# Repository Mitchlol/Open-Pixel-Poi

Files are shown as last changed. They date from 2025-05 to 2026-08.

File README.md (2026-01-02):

<h1>
Open Pixel Poi

</h1>

<h4>
  <a href="https://openpixelpoi.com/">Store</a>
  ·
  <a href="./Firmware/MANUAL.md">User Guide</a>
  ·
  <a href="./Hardware/3D Printable Body/README.md">3D Models</a>
  ·
  <a href="./Hardware/Assembly/README.md">Assembly</a>
  ·
  <a href="./Software/README.md">Mobile App</a>
  ·
  <a href="https://mitchlol.github.io/#openpixelpoi">Firmware Tool</a>
  ·
  <a href="https://discord.gg/WpPJEskEuM">Discord</a>
  ·
  <a href="https://www.instagram.com/openpixelpoi">Instagram</a>
</h4>

Open Pixel Poi  is an open source, 3D printable, LED pixel Poi, based around ESP32, WS2812B, and FFF/FDM manufacturing.
Designed to be simple, afforable, repairable, and customizable.
<div>
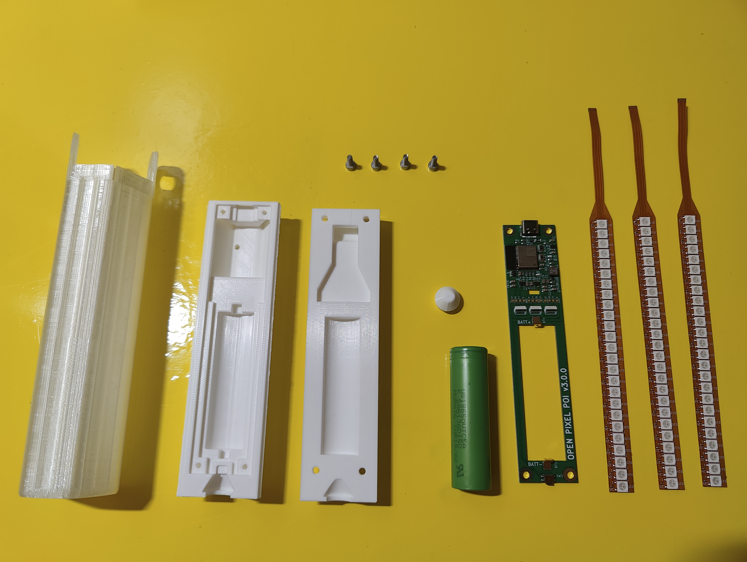
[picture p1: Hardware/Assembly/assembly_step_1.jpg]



</div>

#### License
[Licensed  with GPLv3](https://www.gnu.org/licenses/gpl-3.0.en.html)
Suggested donation of 5$ per set of Poi built via [paypal](https://www.paypal.com/donate/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) when build without purchasing PCBs from our <a href="https://openpixelpoi.com/">Store</a>.

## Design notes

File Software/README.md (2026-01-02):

# Open Pixel Poi Software
<div>





</div>

## About
This app is written using flutter, a multi-platform framework. It is designed to run on mobile sized screens, but will work on anything. Currently, I have built the app for [Android](#android-releases), [Windows](#windows-releases), and [Web](#web-releases).

This app is the only way transmit patterns to the poi hardware.

All patterns are images. To import a new pattern to the app, it must be a bitmap/png/jpg format. Then simply tap/click/etc the pattern to overwrite the currently active pattern on all connected poi. See the [pattern info doc](./PATTERN_INFO.md) for more details.

App use may require a poi [firmware update](https://mitchlol.github.io/#openpixelpoi)

###### Tips & Tricks
- Select multiple devices to connect to multiple devices.
- Long press scan to proceed to app without any connections.
- Long press a pattern to see it's size, or delete/flip/mirror it.
- Selecting the ∞ pattern slot will trigger auto pattern looping.
- Long press the app name on the patterns page to enter the secret [device settings](../Firmware/CONFIG.md) page.
- The text pattern creation input only accepts capital letters.
- When creating stacked patterns, be mindful of the widths, if the least common multiple is greater than 400, it will crop.
- Buy a \$2000 macbook, a \$1000 iphone and a dev license to build the app for iOS.

## Android Releases
###### ⚠️Uninstall the app  before switching versions.⚠️
- [Open Pixel Poi v2.0.0](https://github.com/Mitchlol/Open-Pixel-Poi/raw/refs/heads/main/Software/open_pixel_poi_v2.0.0.apk)
- [Open Pixel Poi v1.0.0](https://github.com/Mitchlol/Open-Pixel-Poi/raw/refs/heads/main/Software/open_pixel_poi_v1.0.0.apk)

## Windows Releases
- [Open Pixel Poi v2.0.0](https://github.com/Mitchlol/Open-Pixel-Poi/raw/refs/heads/main/Software/open_pixel_poi_windows_v2.0.0.zip)
- [Open Pixel Poi v1.0.0](https://github.com/Mitchlol/Open-Pixel-Poi/raw/refs/heads/main/Software/open_pixel_poi_windows_v1.0.0.zip)

## Web Releases
> [!TIP]
> Web bluetooth api is limited to a single device connection at a time.
> Also, it is unspported on iOS 🤦‍♂️.

- [Open Pixel Poi Web v2.0.0](https://mitchlol.github.io/opp_flutter_app_2.0/index.html)
- [Open Pixel Poi Web v1.0.0](https://mitchlol.github.io/opp_flutter_app_1.0/index.html)

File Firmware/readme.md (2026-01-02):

# Open Pixel Poi Firmware

##### Links
- [User Manual](./MANUAL.md)
- [Firmware Flashy Thing](https://mitchlol.github.io/#openpixelpoi)

##### Firmware info
This is the firmware, it is an arduino project designed to be built in platformio.

Platformio should get all the correct dependancies automatically based on the config, but in case it doesn't here are the details.
It uses the neopixelbus library.
It requires the esp32 boards to be installed, I reccomend v2.0.12 as newer versions cause led glitches.
When builiding, use the XIAO_ESP32C3 board for the gpio config to line up. All the other board settings can be default.

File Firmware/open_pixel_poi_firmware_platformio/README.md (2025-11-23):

# Compiling Info
1. Connect your ESP32 PCB to your computer via USB, on windows it should show up as "USB Serial Device (COM#)" with the "#" being a random number.
1. Open this folder up in VSCode with the PlatformIO plugin stalled.
1. Hit the -> arrow button on the bottom bar to compile and upload the firmware to your PCB.

All the library dependencies and board config is contained in the platformio.ini file in this folder.

# Note for self: Export a compiled firmware to web-based firmware flashy tool.
1. Hit the -> arrow button on the bottom bar to compile and upload the firmware to your PCB.
1. copy .pio/build/seeed_xiao_esp32c3/firmware.bin to opp_firmware folder in the mitchlol.github.io project, replacing the old one.
1. update the manifest.json in that same folder with the current date to have some minimal tracking.

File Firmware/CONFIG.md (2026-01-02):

# Notes about the config.h and app overrides

The [config.h](./open_pixel_poi_firmware_platformio/src/config.h) file contains all the constant perameters for the firmware. Most of these should never be changed, unless you are building custom hardware.

Some of the fields however can be changed via the app, such as renaming your device, changing the led quantity or type, or even changing your 6 speed options.

To enter to enter the device settings page, long press the app name on the patterns page.

Settings changed via the app will permanently overwrite the default config.h, unless a full chip erase is done. My firmware flashing webpage does a full erase. The default upload button in platformio does not.

To get a fully custom config, simply change what you need, recompile, and upload.

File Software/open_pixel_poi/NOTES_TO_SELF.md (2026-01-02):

# Dear me
Compiling for web doesn't require any code changes, however web bluetooth doesn't work on your windows desktop, so test with your phone or something else. When releasing a build make sure to update the base url at the top of the index.html in the built web folder. 

Compiling for windows requires switching to flutter_blue_plus_windows see commented out stuff.

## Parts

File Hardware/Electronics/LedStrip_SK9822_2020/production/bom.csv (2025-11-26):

Designator | Footprint | Quantity | Value | LCSC Part #
LED1, LED10, LED11, LED12, LED13, LED14, LED15, LED16, LED17, LED18, LED19, LED2, LED20, LED21, LED22, LED23, LED24, LED25, LED26, LED27, LED28, LED29, LED3, LED30, LED31, LED32, LED33, LED34, LED35, LED36, LED37, LED38, LED39, LED4, LED40, LED41, LED42, LED43, LED44, LED45, LED46, LED47, LED48, LED49, LED5, LED50, LED51, LED52, LED53, LED54, LED55, LED6, LED7, LED8, LED9 | LED-SMD_6P-L2.0-W2.0-P0.80-TL | 55 | SK9822-EC20 | C2909059

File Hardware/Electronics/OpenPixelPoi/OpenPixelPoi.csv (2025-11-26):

Id | Designator | Footprint | Quantity | Designation | Supplier and ref
1 | C6,C7 | C_0402_1005Metric | 2 | 22u
2 | R5 | R_0603_1608Metric | 1 | 1k
3 | R4 | R_0603_1608Metric | 1 | 10k
4 | C1 | C_0805_2012Metric | 1 | 100n
5 | U3 | ESP32-C3-MINI-1_EXP | 1 | ESP32-C3-MINI-1-N4
6 | SW2,SW1 | SW_SPST_B3U-1000P | 2 | SW_Push
7 | J1 | JST_PH_B3B-PH-K_1x03_P2.00mm_Vertical | 1 | Conn_01x03_Socket
8 | R2,R1 | R_0603_1608Metric | 2 | 5k1
9 | U5 | SOT-223-3_TabPin2 | 1 | TLV1117-33
10 | F1 | Fuse_1206_3216Metric | 1 | Polyfuse_Small (1A)
11 | U1 | SOT-666 | 1 | USBLC6-2P6
12 | D1 | LED_0603_1608Metric | 1 | LED
13 | SW3 | Panasonic_EVQPUL_EVQPUC | 1 | SW_Push
14 | R3 | R_0603_1608Metric | 1 | 100k
15 | J6 | USB_C_Receptacle_HRO_TYPE-C-31-M-12 | 1 | USB_C_Receptacle_USB2.0_16P
16 | Q1 | SOT-23 | 1 | BSS138

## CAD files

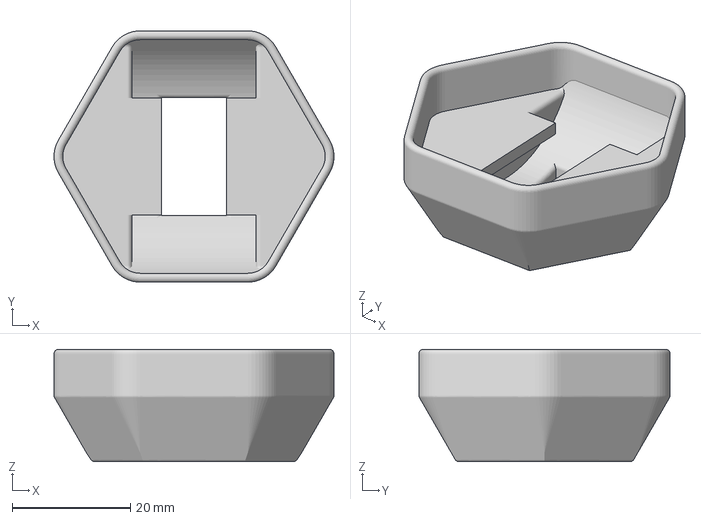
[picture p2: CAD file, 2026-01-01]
Hardware/3D Printable Body/Extras/Open Pixel Poi - Shell Cap - Hex.3mf
47.4 x 42.5 x 19.0 mm

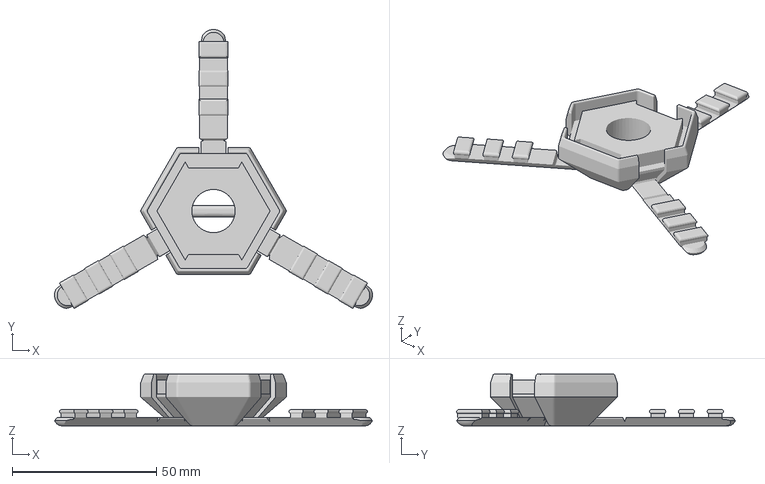
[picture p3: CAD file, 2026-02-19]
Hardware/3D Printable Body/Open Pixel Poi - Shell Cap - Snap B.3mf
110.3 x 96.8 x 18.0 mm

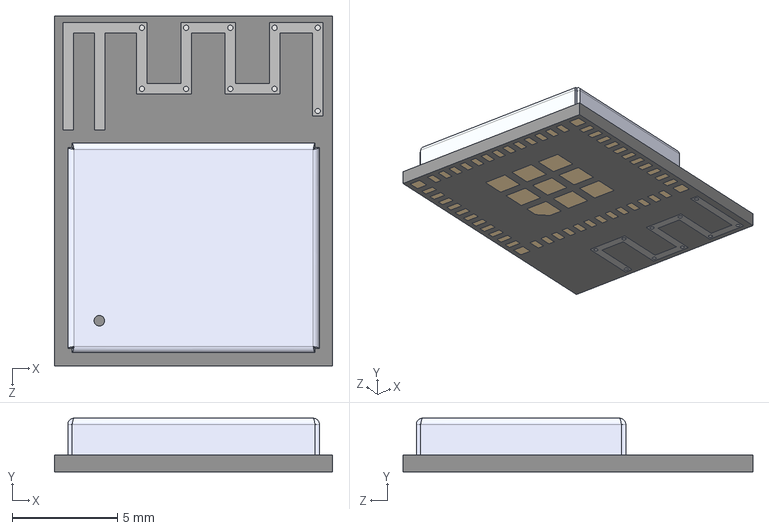
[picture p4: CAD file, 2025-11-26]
Hardware/Electronics/OpenPixelPoi/ESP32_C3_MINI_1_N4 (v2)/ESP32-C3-MINI-1-N4.step
13.2 x 2.55 x 16.6 mm

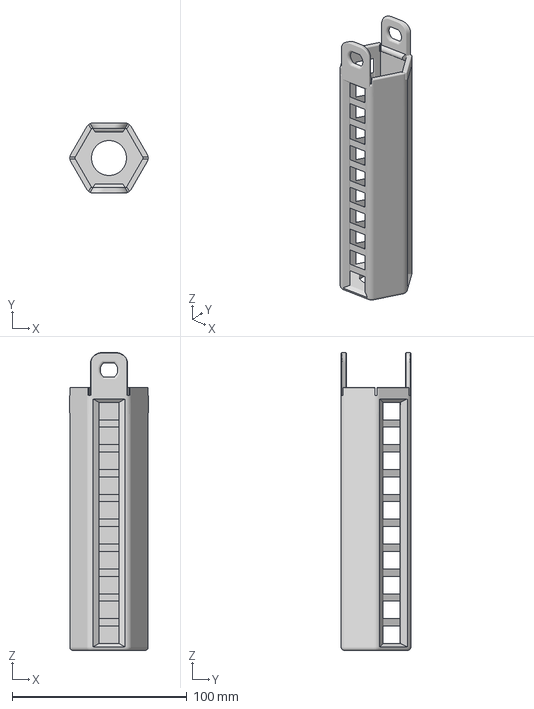
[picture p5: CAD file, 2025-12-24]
Hardware/3D Printable Body/Extras/Open Pixel Poi - Shell - Hex Holes - 55 Pixel.3mf
44.9 x 40.0 x 170.5 mm

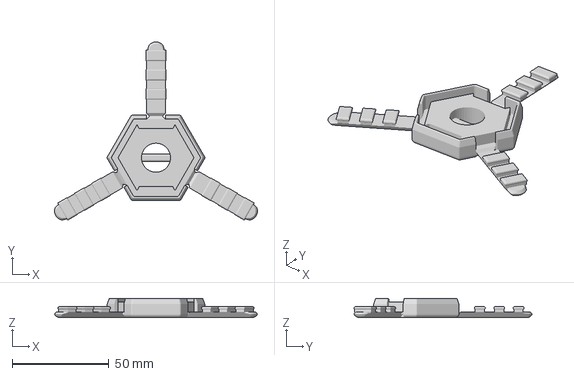
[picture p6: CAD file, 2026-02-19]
Hardware/3D Printable Body/Open Pixel Poi - Shell Cap - Snap A.3mf
104.9 x 92.1 x 10.0 mm

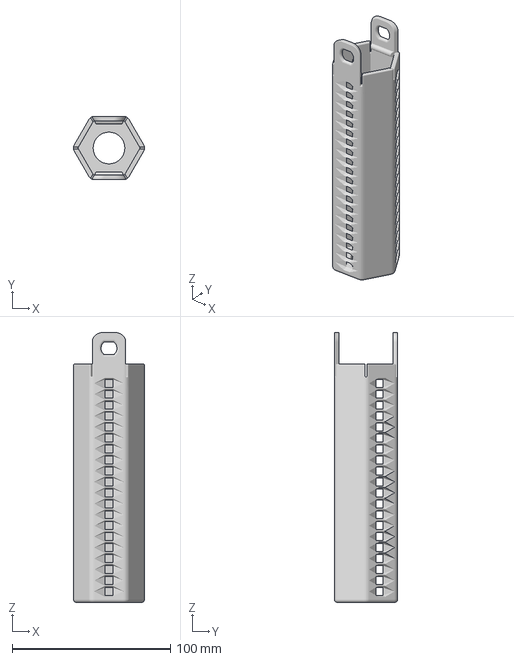
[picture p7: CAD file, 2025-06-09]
Hardware/3D Printable Body/Extras/Open Pixel Poi - Shell - Hex Holes.3mf
45.0 x 40.0 x 170.5 mm

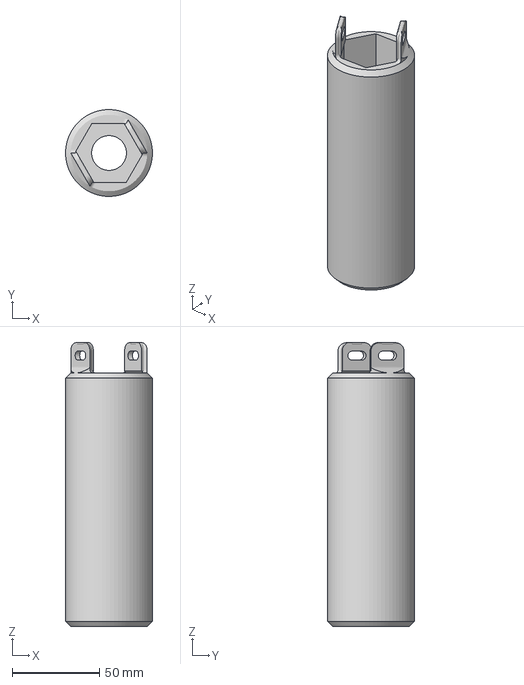
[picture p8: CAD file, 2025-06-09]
Hardware/3D Printable Body/Extras/Open Pixel Poi - Shell - Round Superdiffuser.3mf
49.9 x 49.9 x 163.0 mm

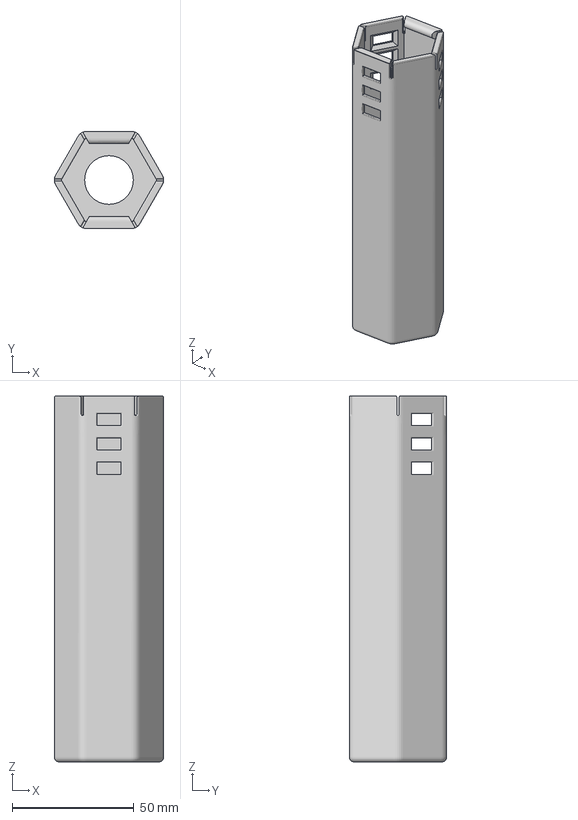
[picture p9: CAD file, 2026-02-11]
Hardware/3D Printable Body/Open Pixel Poi - Shell - Snap.3mf
45.0 x 40.0 x 150.5 mm

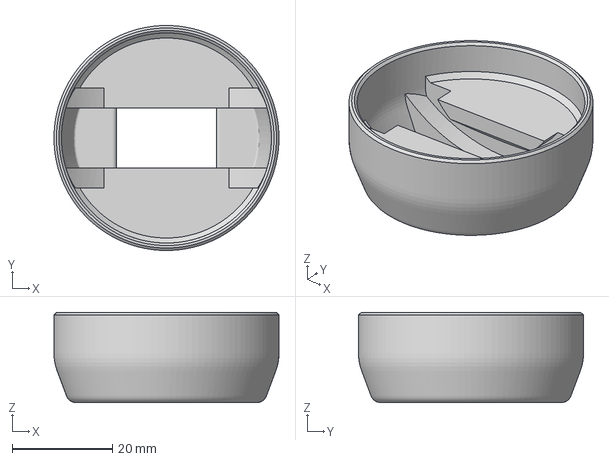
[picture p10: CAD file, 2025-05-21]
Hardware/3D Printable Body/Extras/Open Pixel Poi - Shell Cap - Round.3mf
45.0 x 45.0 x 18.0 mm

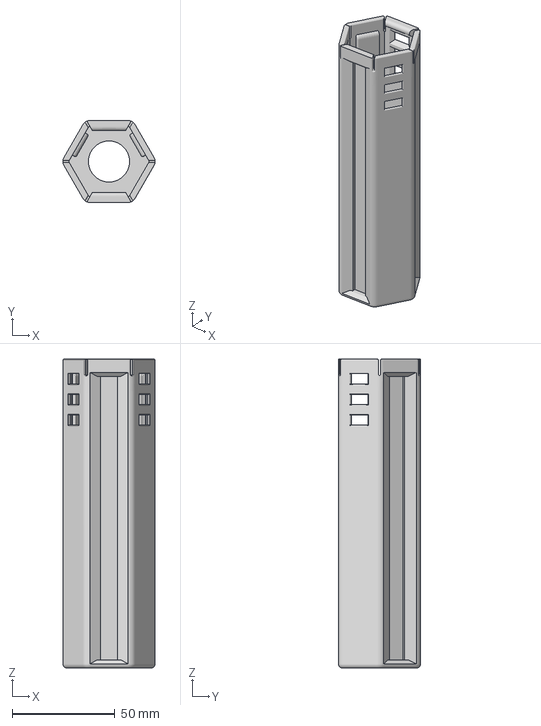
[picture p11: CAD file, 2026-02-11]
Hardware/3D Printable Body/Open Pixel Poi - Shell - Snap - 55 Pixel.3mf
45.0 x 40.0 x 150.5 mm

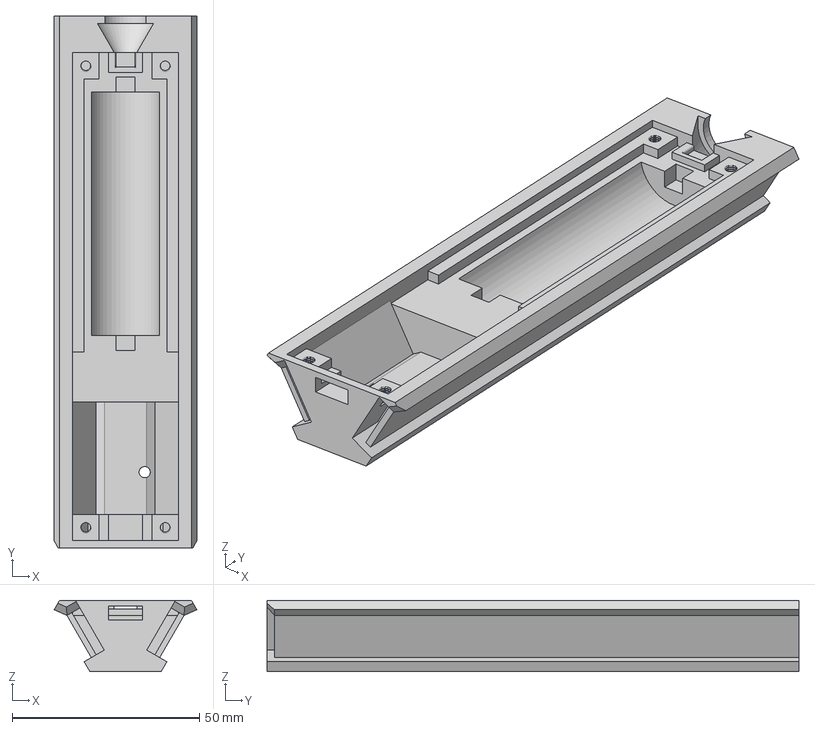
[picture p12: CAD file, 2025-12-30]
Hardware/3D Printable Body/Open Pixel Poi - Body - Top.3mf
38.1 x 142.0 x 19.0 mm

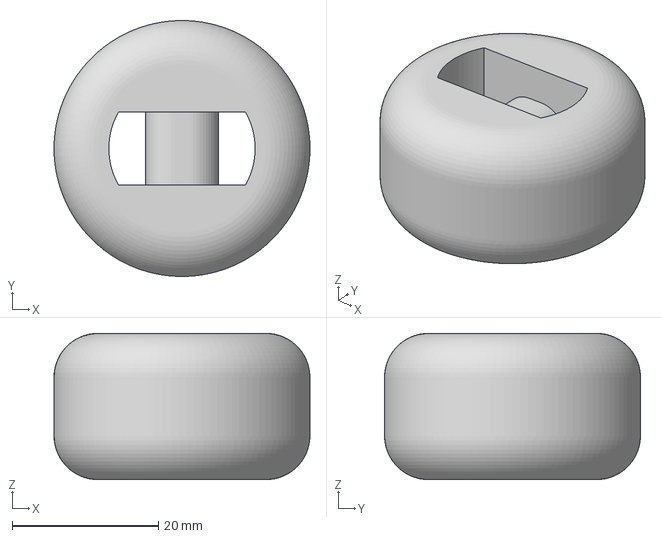
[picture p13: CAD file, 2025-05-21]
Hardware/3D Printable Body/Extras/Poi Knob v2.3mf
35.0 x 35.0 x 20.0 mm

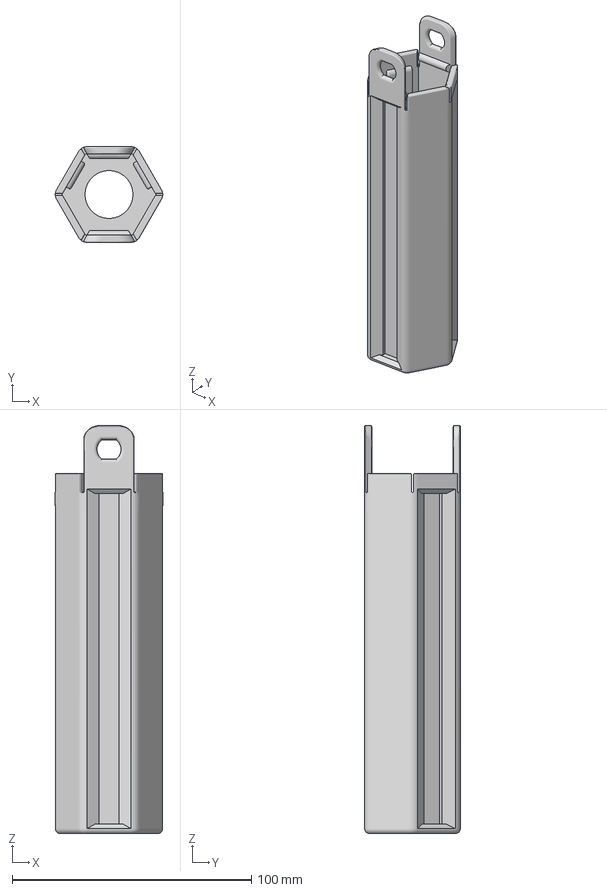
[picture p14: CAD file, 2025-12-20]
Hardware/3D Printable Body/Open Pixel Poi - Shell - Hex - 55 Pixel.3mf
45.0 x 40.0 x 170.5 mm

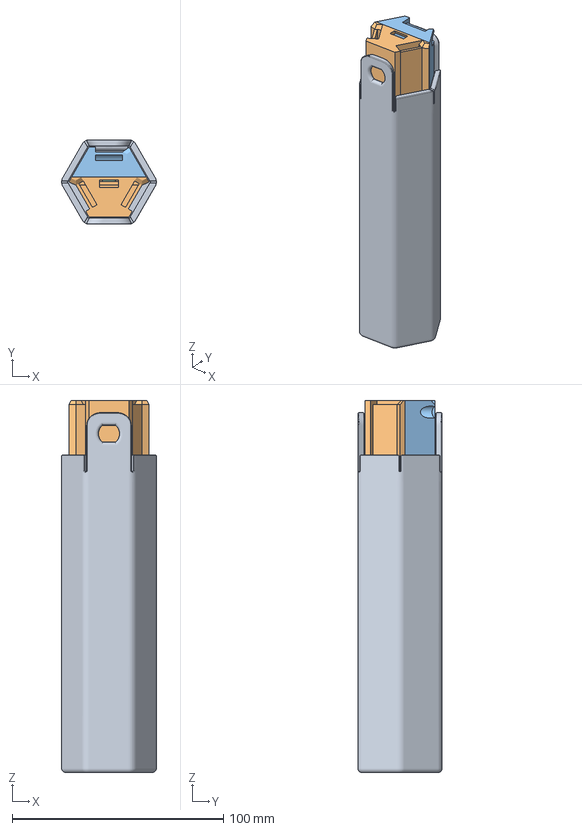
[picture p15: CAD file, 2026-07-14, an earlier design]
Hardware/3D Printable Body/OldFiles/Open Pixel Poi - All Parts In One File.3mf
45.0 x 40.0 x 176.2 mm

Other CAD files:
Hardware/3D Printable Body/Open Pixel Poi - Shell Cap - Snap C.3mf
Hardware/3D Printable Body/OldFiles/Open Pixel Poi - Shell - Hex.3mf
Hardware/3D Printable Body/OldFiles/Open Pixel Poi - Shell - Round Diffused.3mf
Hardware/3D Printable Body/Extras/Poi Knob v1.3mf

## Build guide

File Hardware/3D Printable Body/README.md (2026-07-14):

# Open Pixel Poi - 3D Printed Body

## Main Body
Print all the main body parts in **PLA** or any other rigid material. Slicer profiles such as layer height an infill are not important, just make sure you can do the overhangs. The individual body files have been pre-oriented so that no supports/brims/rafts/etc are required, see the section on orientation below to confirm your orientation. You need 1 of each part per poi, or 2 of each for a pair.
###### Main body parts are:
1. [Open Pixel Poi - Body - Top](<https://github.com/Mitchlol/Open-Pixel-Poi/raw/refs/heads/main/Hardware/3D%20Printable%20Body/Open%20Pixel%20Poi%20-%20Body%20-%20Top.3mf>)
1. [Open Pixel Poi - Body - Bottom](<https://github.com/Mitchlol/Open-Pixel-Poi/raw/refs/heads/main/Hardware/3D%20Printable%20Body/Open%20Pixel%20Poi%20-%20Body%20-%20Bottom.3mf>)
1. [Open Pixel Poi - Body - Button](<https://github.com/Mitchlol/Open-Pixel-Poi/raw/refs/heads/main/Hardware/3D%20Printable%20Body/Open%20Pixel%20Poi%20-%20Body%20-%20Button.3mf>)

## Outer Shell
The outer shell must be printed in **Clear / Transparent TPU**. All shell files are preoriented and do not require any supports/brims/rafts/etc, but I reccomend the "avoid crossing perimiters" settings to reduce stringing. See the section on orientation below to confirm your orientation. The shells look nice in 10% gyroid or 3d honeycomb infill IMO. You need 1 shell & 1 cap per poi, so that means 4 parts for a pair.

For the cap, pick whichever version you preffer, they are all cross compatible. If you want a different mounting situation on these caps, and don't know how to model it yourself, send a message in the discord channel, and I can likely help you out.

###### Shells versions are:
1. **25 Pixel (Standard) Shell:** [Open Pixel Poi - Shell - Snap](<https://github.com/Mitchlol/Open-Pixel-Poi/raw/refs/heads/main/Hardware/3D%20Printable%20Body/Open%20Pixel%20Poi%20-%20Shell%20-%20Snap.3mf>)
1. **55 Pixel (HD) Shell:** [Open Pixel Poi - Shell - Snap - 55 Pixel](<https://github.com/Mitchlol/Open-Pixel-Poi/raw/refs/heads/main/Hardware/3D%20Printable%20Body/Open%20Pixel%20Poi%20-%20Shell%20-%20Snap%20-%2055%20Pixel.3mf>)

###### Cap options are:
1. **Snap Cap Flat:** [Open Pixel Poi - Shell Cap - Snap A](<https://github.com/Mitchlol/Open-Pixel-Poi/raw/refs/heads/main/Hardware/3D%20Printable%20Body/Open%20Pixel%20Poi%20-%20Shell%20Cap%20-%20Snap%20A.3mf>)
1. **Snap Cap Tapered:** [Open Pixel Poi - Shell Cap - Snap B](<https://github.com/Mitchlol/Open-Pixel-Poi/raw/refs/heads/main/Hardware/3D%20Printable%20Body/Open%20Pixel%20Poi%20-%20Shell%20Cap%20-%20Snap%20B.3mf>)
1. **Snap Cap Tapered 6.75mm Though-Hole:** [Open Pixel Poi - Shell Cap - Snap C](<https://github.com/Mitchlol/Open-Pixel-Poi/raw/refs/heads/main/Hardware/3D%20Printable%20Body/Open%20Pixel%20Poi%20-%20Shell%20Cap%20-%20Snap%20C.3mf>)

## Orientation
The parts all print without supports when oriented like this. Take special note of orientation the bottom half of the body, the led groove is an overhang rather than requiring supports.

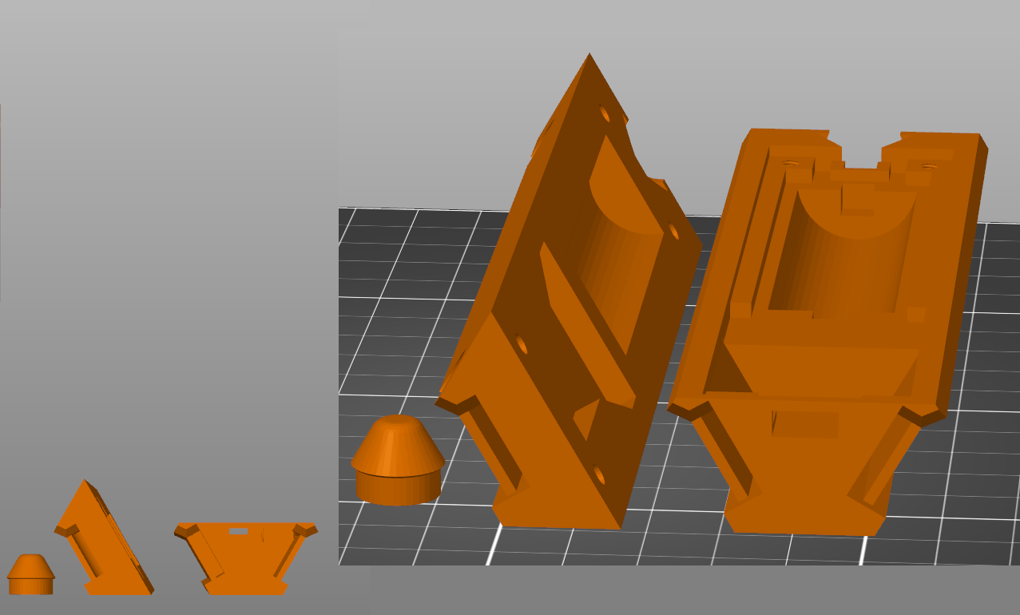
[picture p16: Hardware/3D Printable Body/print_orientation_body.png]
Body orientation
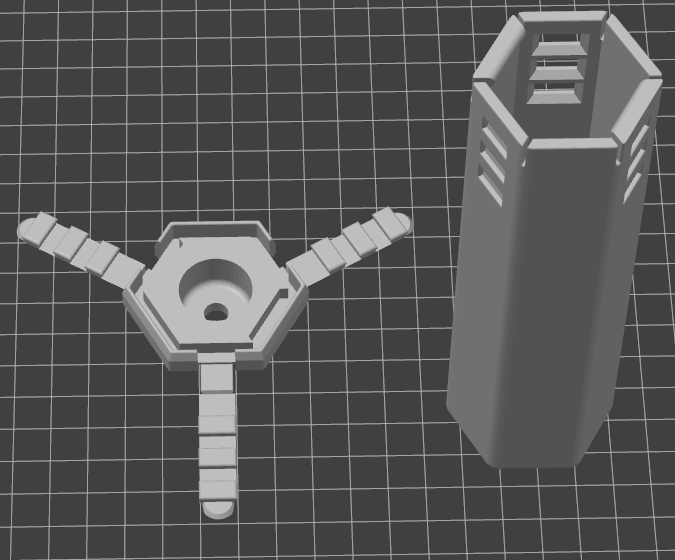
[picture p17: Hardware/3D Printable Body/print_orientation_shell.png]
Shell orientation


## Extras
The [Extras](./Extras/README.md) folder contains poi knobs, and whatever else seems relevant to upload. Nothing in this folder is required to have a functional poi, but it is worth having a look.

## OldFiles
If you are looking for the older shell files, they are now deprecated, but I dumped them all in the [OldFiles folder](./OldFiles)

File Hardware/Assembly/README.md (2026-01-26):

# Open Pixel Poi Assembly Guide

## intro

This is basic assembly guide, and while assembly should be intuitive, this guide includes a few tips, tricks, and order of operations optimizations.

Assembly is identical for both the 25 & 55 pixel LED strips. If you wish to solder your own LED strips or have a 2.2.1 version of the kit, see the <a href="./2.2.1/README.md">2.2.1 Assembly Guide</a> 

## Step 1: 
### Gather your parts
For a single poi you will need:
1. 3D Printed outer shell (clear TPU) - 1x
1. 3D Printed body top (PLA) - 1x
1. 3D Printed body bottom (PLA) - 1x
1. 3D Printed button (PLA) - 1x
1. M3 x 8mm Hex Socket Head Cap Screw - 4x
1. 18650 Li-Ion battery - 1x
1. Open Pixel Poi PCB - 1x
1. Open Pixel Poi LED Strip - 3x

wiring

## Step 2
### Insert 2 led stips. 
Feed 2 led strips in though the holes at the top of the 3D printed top body piece.
wiring

## Step 3
### Connect 2 LED strips to the PCB
Ensure the black levers on the connectors are lifted up (perpendicular) from the PCB.  
Insert the FPC(ribbon cable) connections into the 2 outer connectors.  
Be gentle, minimal force is required, if it catches on something, pull back and try again.  
Secure the ribbon cables by rotating/folding/pushing the black levers down, so they are parallel with the board.  
The LED connections work both ways (like USB-C). I reccomend matching the directions in the photo with the yellow background to avoid twists.  
Look at the 2nd photo with red markings for a generic close up view of the insertion and lever mechanism.  
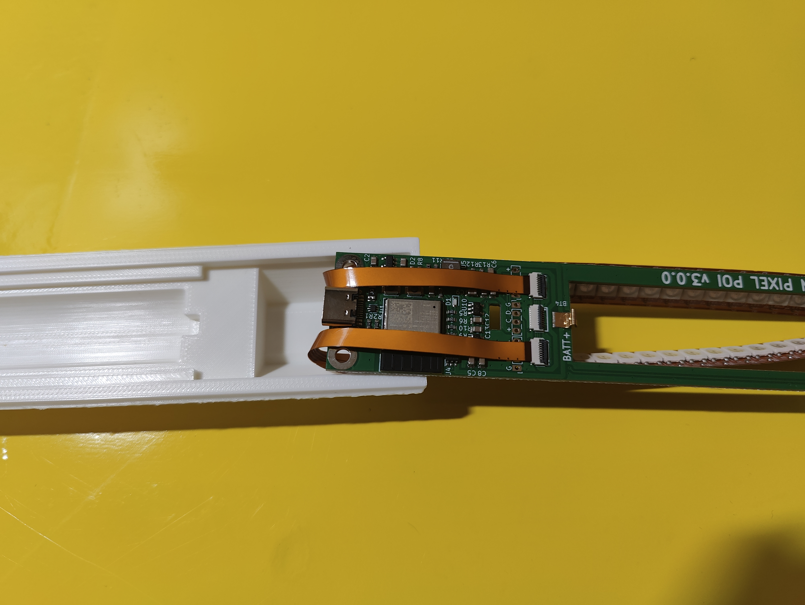
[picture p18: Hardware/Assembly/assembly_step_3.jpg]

wiring

## Step 4
### Thread 3rd led strip through the PCB
Thread 3rd led strip through the small hole in the PCB.  
Give yourself plenty of slack.  
wiring

## Step 5
### Connect the 3rd LED strip to the PCB
Same as step 3, but using the middle connector.  
Once connected, pull the slack back through the hole in the PCB.  
The LED connections work both ways (like USB-C). I reccomend matching the directions in the photos to avoid twists.  
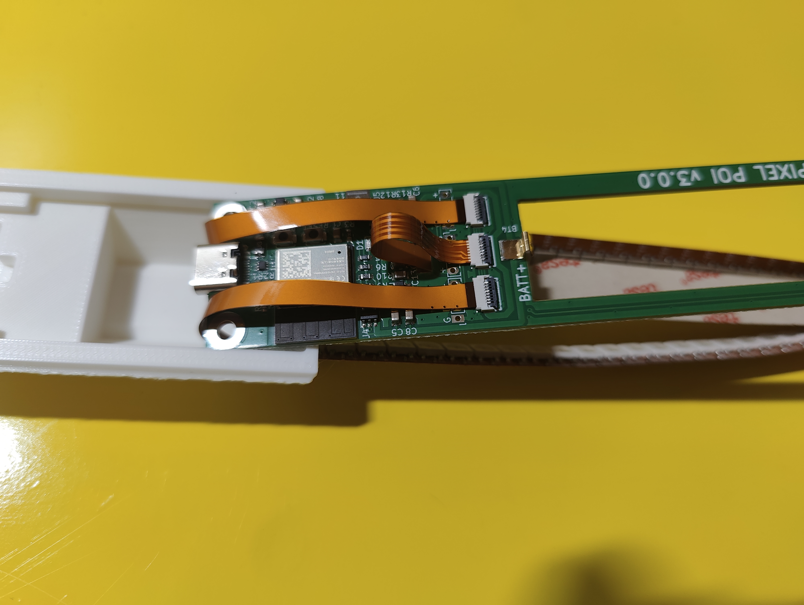
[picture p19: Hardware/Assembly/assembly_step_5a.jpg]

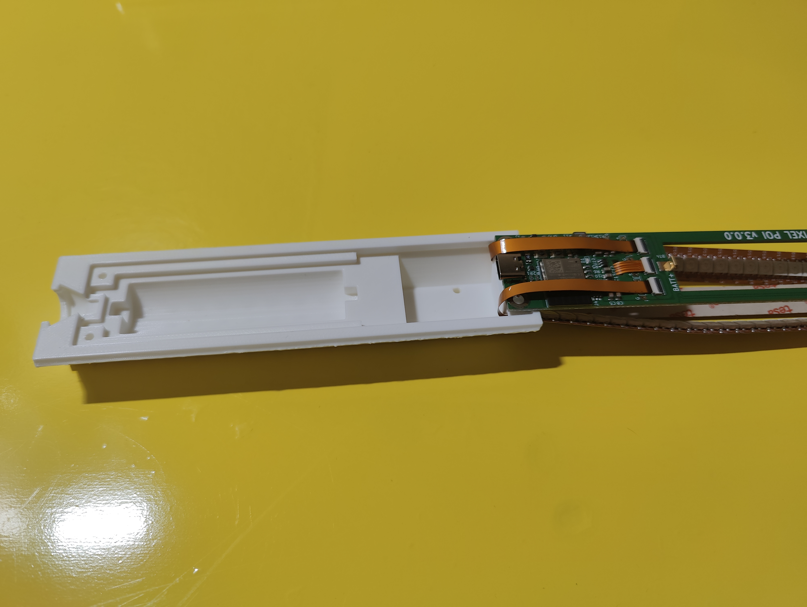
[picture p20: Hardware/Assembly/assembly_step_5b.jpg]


## Step 6
### Insert the battery into the top of the body
Push the battery into the body, making sure the positive end is towards the USB port, and lines up with the batt+ label on the board.  
It is a tight fit, this is intentional.  
It goes in easiest if you slide it in all at once, rather than one end first.  
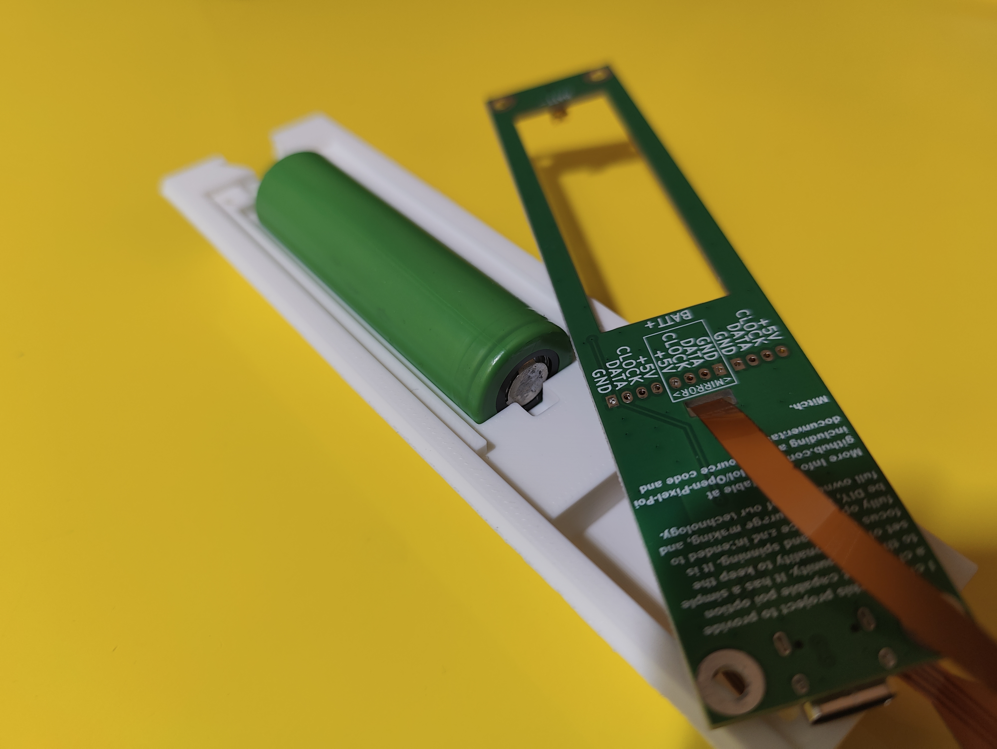
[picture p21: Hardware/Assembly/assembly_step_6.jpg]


## Step 7
### Slot in the PCB
Order is important here.  
First slide the usb port into the usb port hole at the top of the poi, while keeping the switch end of the board elevated.  
Then, carefully lever down the board over the battery, this will turn the poi on.  
Finally, make sure the bottom (and sides) of the pcb are fully seated and flush with the body.  
This is often tight as well and may snap in.  
You can turn the poi off with the switch see the [user manual](../../Firmware/MANUAL.md)
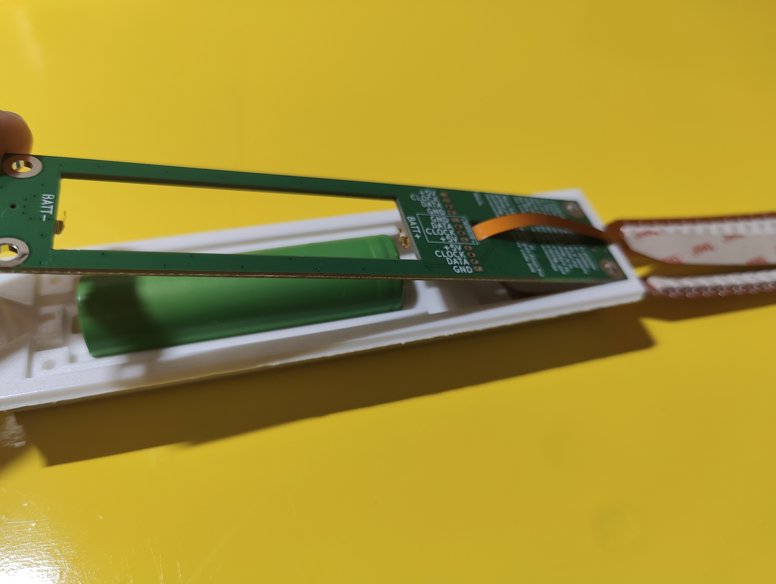
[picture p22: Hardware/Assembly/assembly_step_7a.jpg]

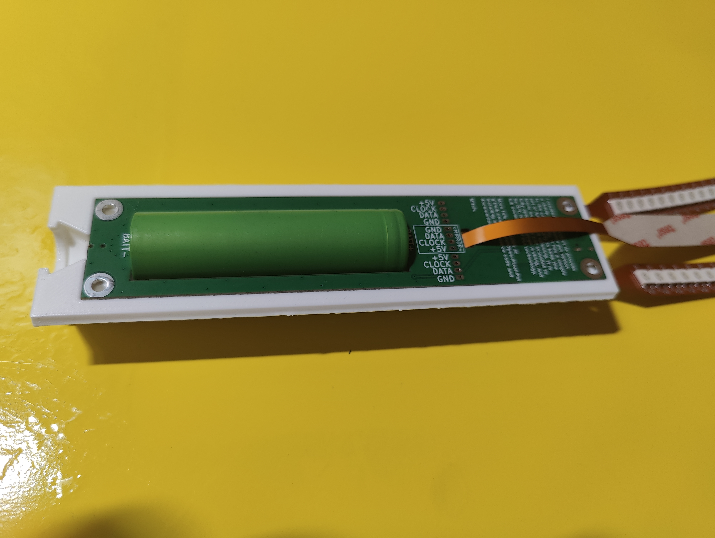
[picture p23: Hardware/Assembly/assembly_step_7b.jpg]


## Step 8
### Snap the button into body
Push the button into the body, it is a snap fit.
> [!CAUTION]
> **Take extra care to avoid contact with the switch on bottom of the board!**
> **It can break easy.**

> [!TIP]
> After writing this guide, I came across a potentialy safer alternative assembly method. Place the button in before putting the PCB in, then hold the body vertically such that gravity lets the button fall to the down position. Then snap the board in without fear of tearing the switch off the pcb, as gravity holds the button away. Maybe this will be useful if someone is assembling many kits.

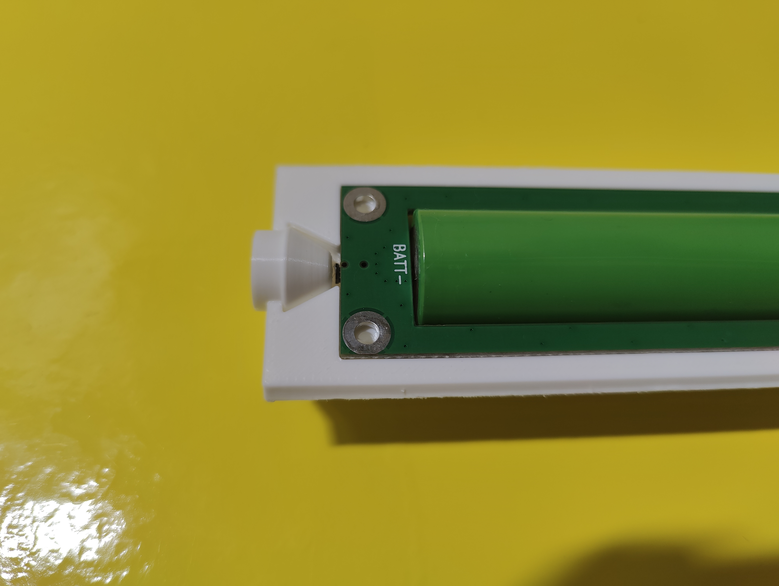
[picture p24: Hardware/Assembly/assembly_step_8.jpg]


## Step 9
### Thread the 3rd led strip through the bottom of the body
Thread the 3rd led strip through the hole at the top of the bottom body half, from the inside to out, make sure it is twisted the right way.
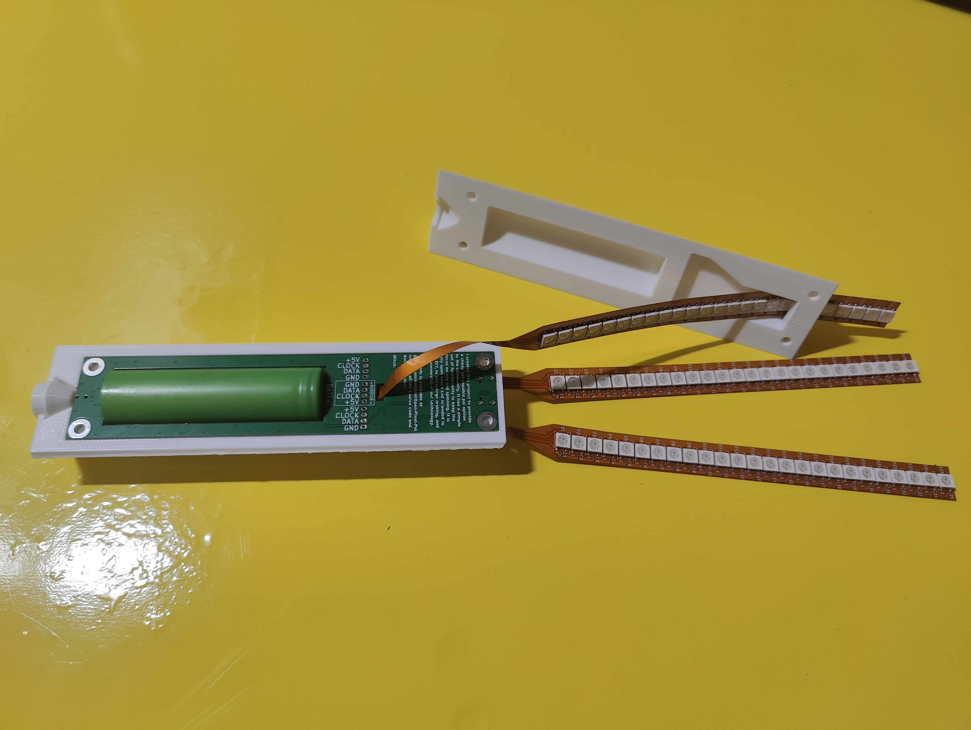
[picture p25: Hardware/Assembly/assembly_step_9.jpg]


## Step 10
### Push the 2 body halves together
Once again, the battery is snug. Make sure the LED stips don's get pinched.
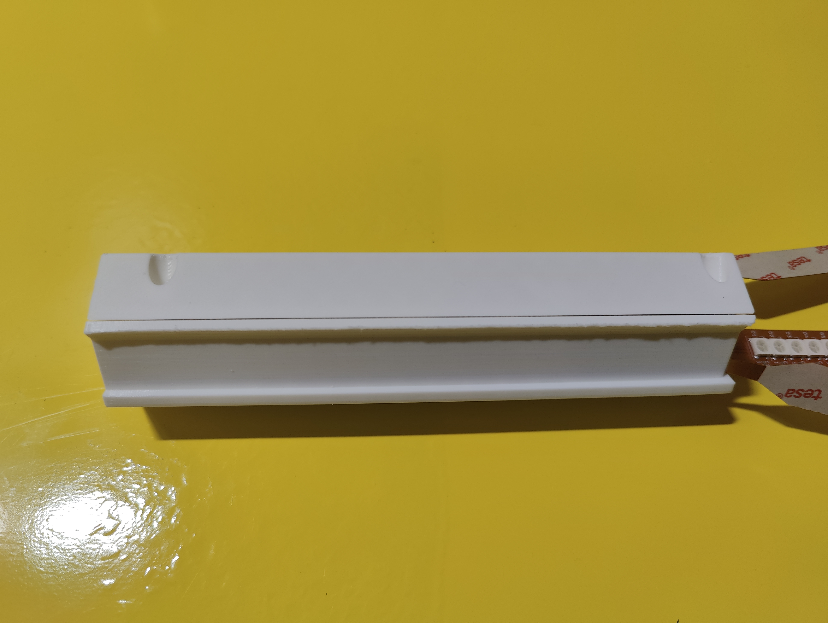
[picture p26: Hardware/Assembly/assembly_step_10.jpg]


## Step 11
### Screw the two halves together
These screws are going directly into a 3d print, so be gentle, you don't want to strip the threads. You can hold it up to the light to make sure there is no visible gap between the 2 halfs, to know it is snug.

Alternativley, you can just wrap the sucker in packing tape, just make sure you do it after sticking on the LEDs.
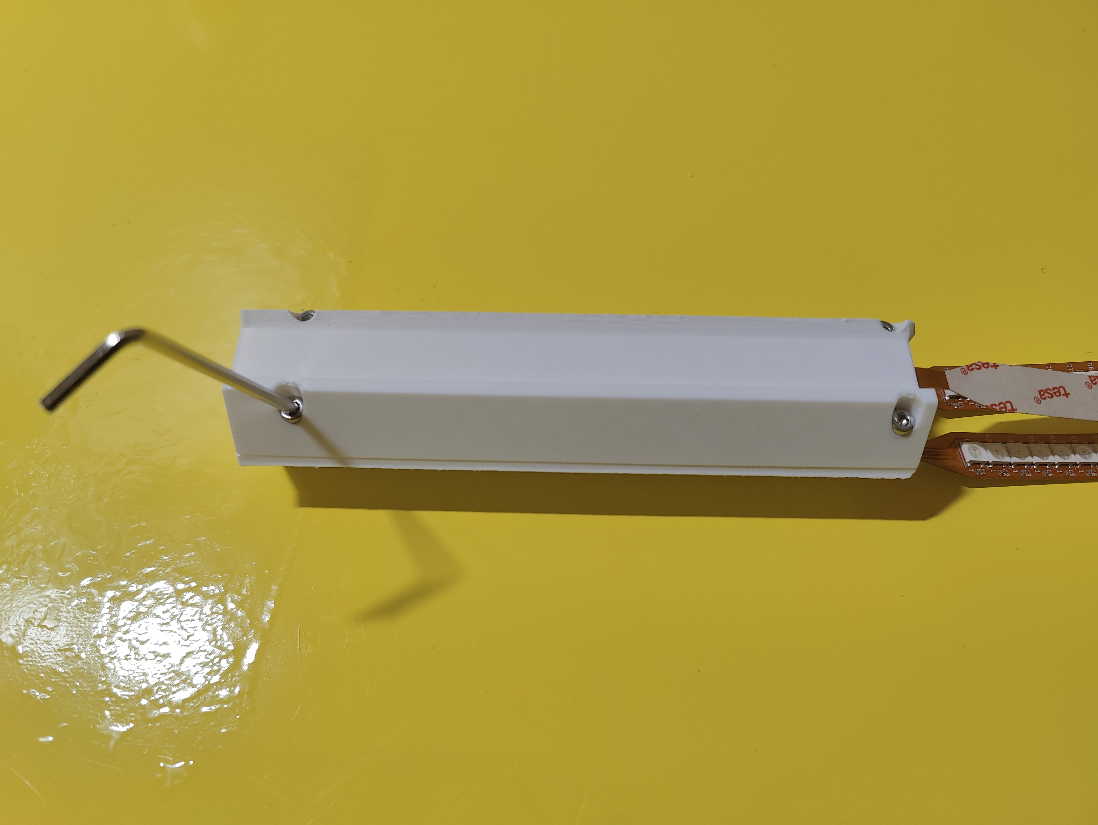
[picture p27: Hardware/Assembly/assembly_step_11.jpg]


## Step 12
### Apply the LED strips
Peel the backing off the LED strips, and apply to the to body. 
One for each recess.  
Start from the bottom of the poi (by the botton) and work back towards the top.  
If you leave about 0.5mm space at the bottom, it should line up perfectly, and prevent accidental peeling.  
Do this for all 3 strips.  
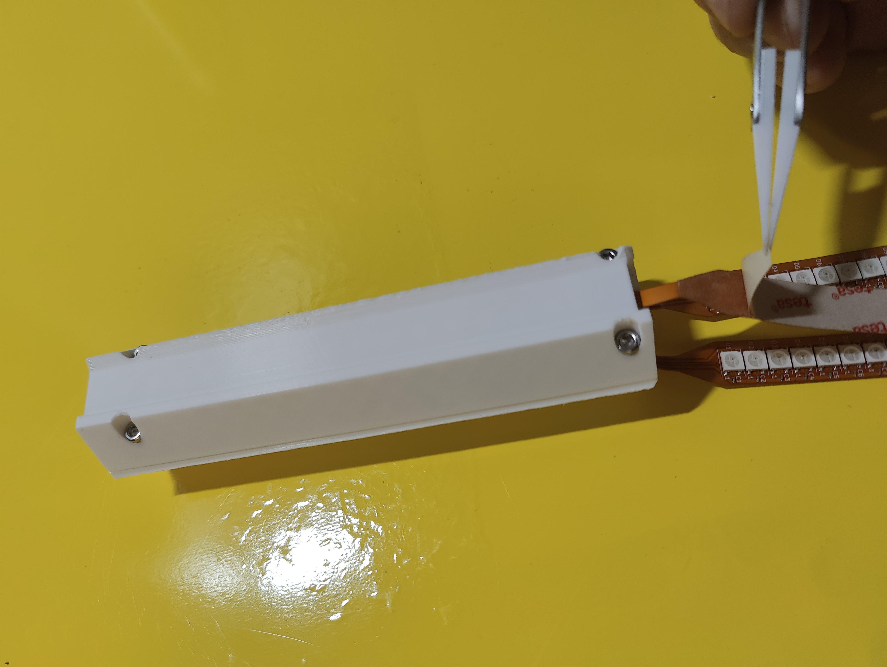
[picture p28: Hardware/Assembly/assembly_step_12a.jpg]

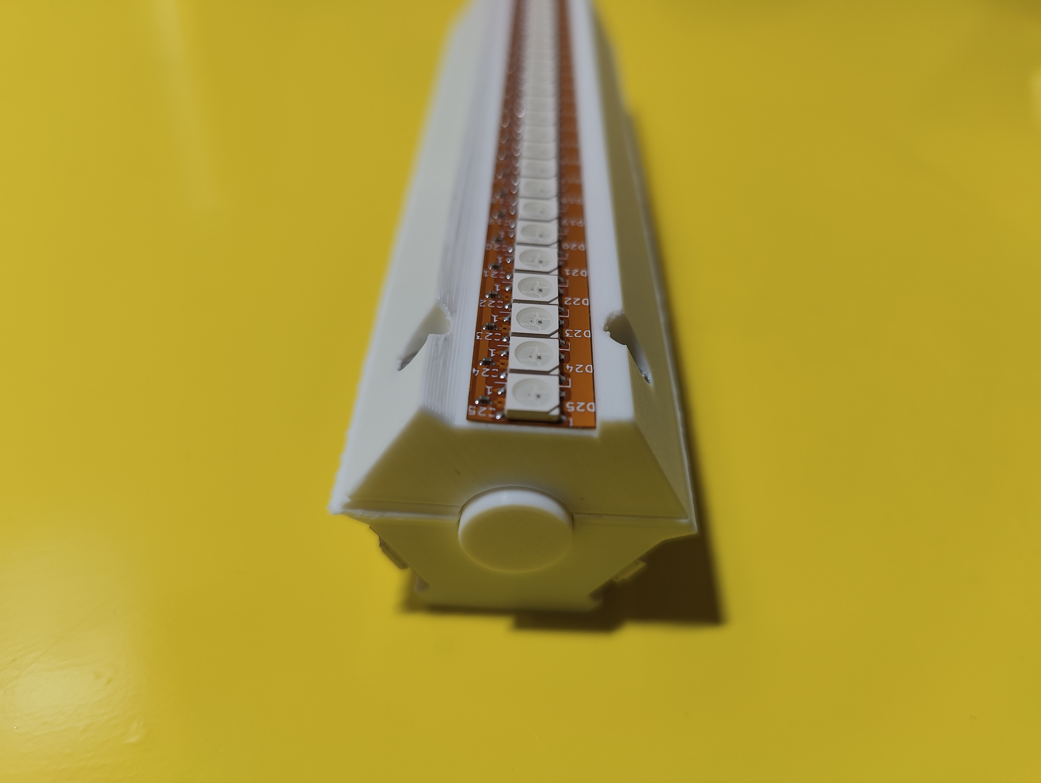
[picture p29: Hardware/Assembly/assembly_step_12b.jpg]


## Step 13
### Tuck excess led strip into the body
Start with your hands, and feed the stips into the holes.  
Fold the strips tightly around the plastic edge.  
Use blunt tweezers to help apply the adhesive inside the holes.  
wiring

## Step 14
### Slot the body into the shell
Pull the two longer tabs apart to get the clearnace needed.
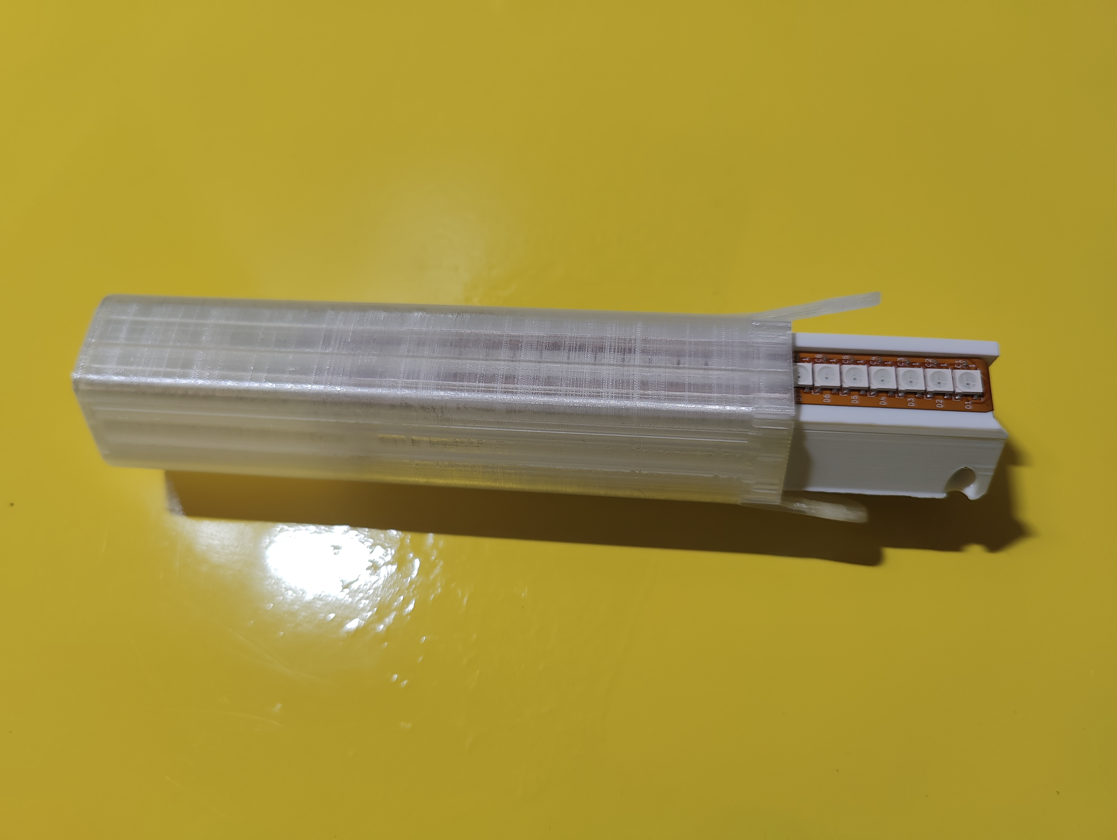
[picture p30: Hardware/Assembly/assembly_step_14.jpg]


## Step 15
### Party!
> [!NOTE]
> I reccomend doing a <a href="https://mitchlol.github.io/#openpixelpoi">Firmware update</a>. The newest firmware fixes a timing issue that can cause poi to drift out of sync. At the time of writing that is the only change from the currently shipping units. 

Woah! Where did that 2nd poi come from?
wiring

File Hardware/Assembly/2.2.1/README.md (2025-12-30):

# Open Pixel Poi Assembly Guide

## intro

This is basic assembly guide, and while assembly should be intuitive, this guide includes a few tips, tricks, and order of operations optimizations. It does not include any soldering specific info.

For a detailed soldering video click [here](https://www.youtube.com/watch?v=ispkQVDGiHQ).

For a realtime assembly video with soldering click [here](https://youtu.be/lT4Q7nI5Dq8?si=qJWZAIUzumP1a3XG).

## Step 1: 
### Gather your parts
For a single poi you will need:
1. 3D Printed outer shell (clear TPU) - 1x
1. 3D Printed body top (PLA) - 1x
1. 3D Printed body bottom (PLA) - 1x
1. 3D Printed button (PLA) - 1x
1. M3 x 8mm Hex Socket Head Cap Screw - 4x
1. 18650 Li-Ion battery - 1x
1. Open Pixel Poi PCB - 1x
1. WS2812b 144/m adhesive back stip 20 leds long (no waterproofing) - 3x
1. 26 AWG Silicone Stranded wire 2.75" long - 9x (3 colors, 3 of each)

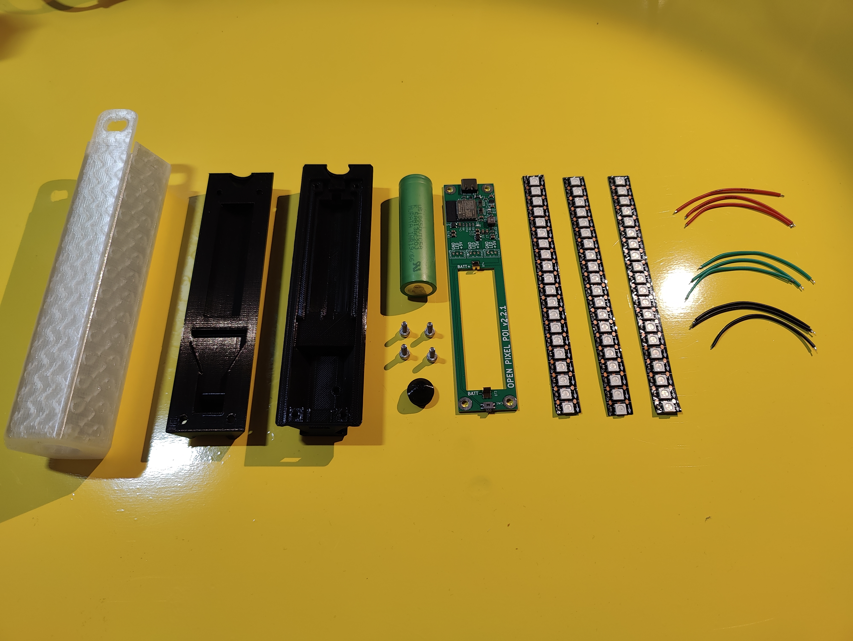
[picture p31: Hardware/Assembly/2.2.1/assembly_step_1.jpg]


## Step 2
### Solder wires to the LED strips
While any color will work, using the right color keeps things neat!  
Black = ground  
Red = power  
Any other color =  data  
wiring

## Step 3
### Solder 2 LED strips to the top of the board
One strip to each of the 2 outer connection points.
You can thread the wires thorugh the holes if you like, but if you don't,
make sure they go away from the battery and towards the USB port.

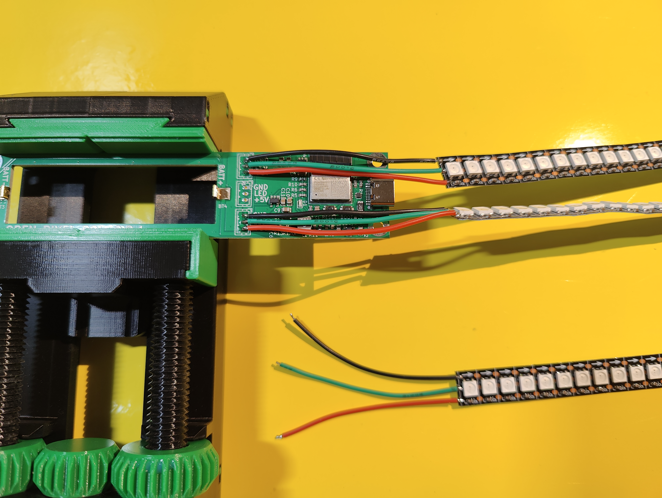
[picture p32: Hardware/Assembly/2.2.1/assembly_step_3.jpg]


## Step 4
### Solder the 3rd LED strip to the bottom of the middle connection
Same as step 3, just using the middle connection on the bottom side of the board.
wiring

## Step 5
### Thread 2 LED strips through the top part of the poi body
The top body part is the one with holes for 2 led strips!
You need to bend them a little to get it through, but you can do it!
Take note that they aren't crossed, and that they are twisted the right way to point outward when folded down.
You can twist the wiring later if you get it wrong, but it is a pain.
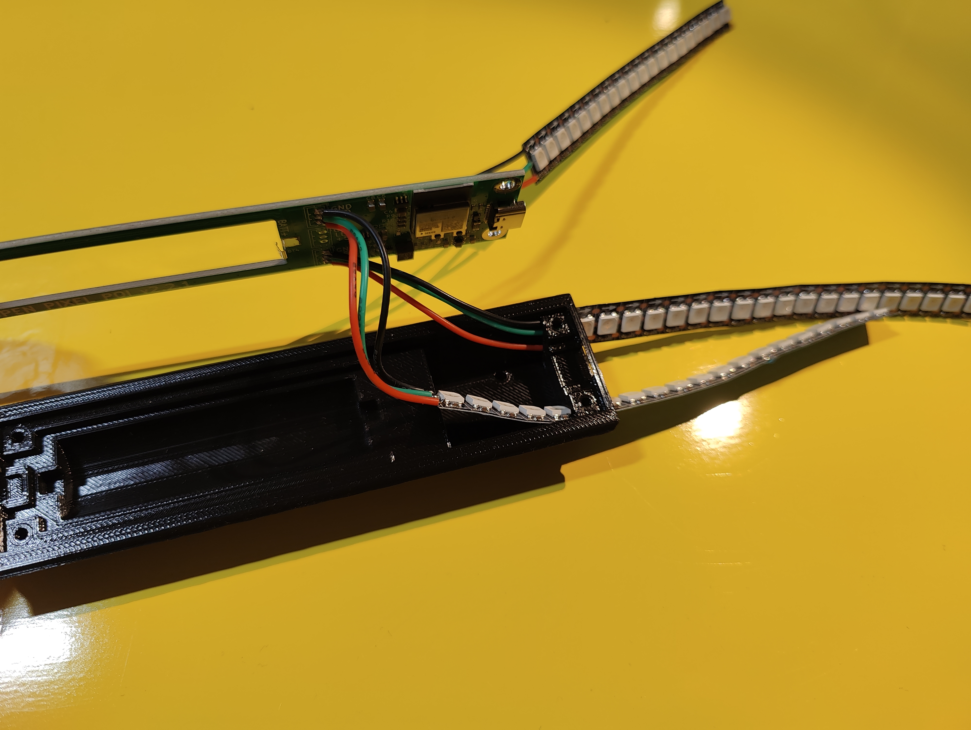
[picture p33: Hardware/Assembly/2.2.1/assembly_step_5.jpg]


## Step 6
### Insert the battery into the top of the body
Push the battery into the body, making sure the positive end is towards the USB port, and lines up with the batt+ label on the board.
It is a tight fit, this is intentional.
It goes in easiest if you slide it in all at once, rather than one end first.
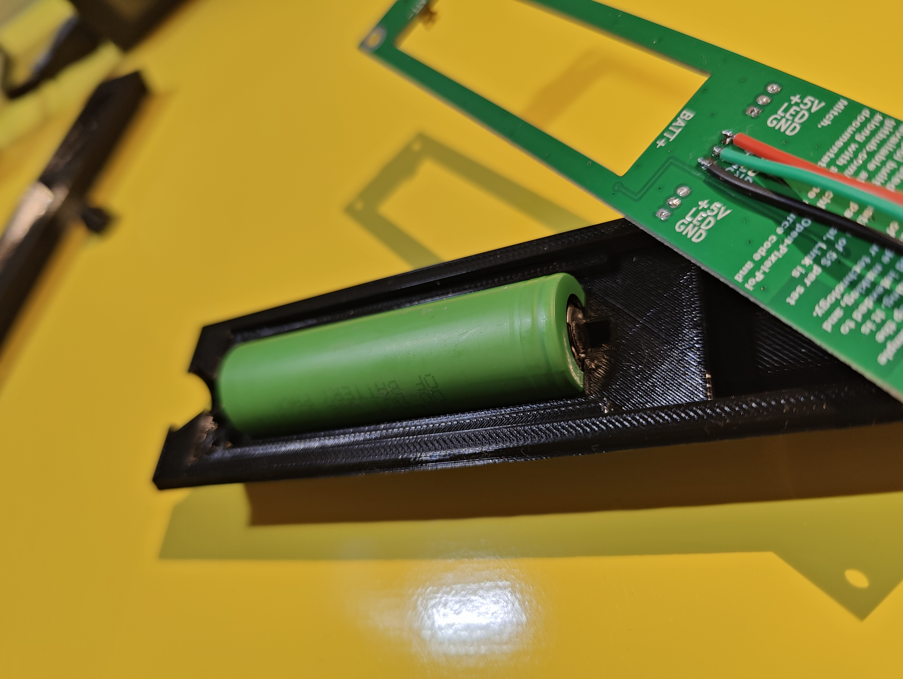
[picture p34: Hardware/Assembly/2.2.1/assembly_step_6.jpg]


## Step 7
### Slot in the PCB
Order is important here.
First slide the usb port into the usb port hole at the top of the poi, while keeping the switch end of the board elevated.
Then, carefully lever down the board over the battery, this will turn the poi on.
Finally, make sure the bottom (and sides) of the pcb are fully seated and flush with the body.
This is often tight as well and may snap in.
You can turn the poi off with the switch see the [user manual]()
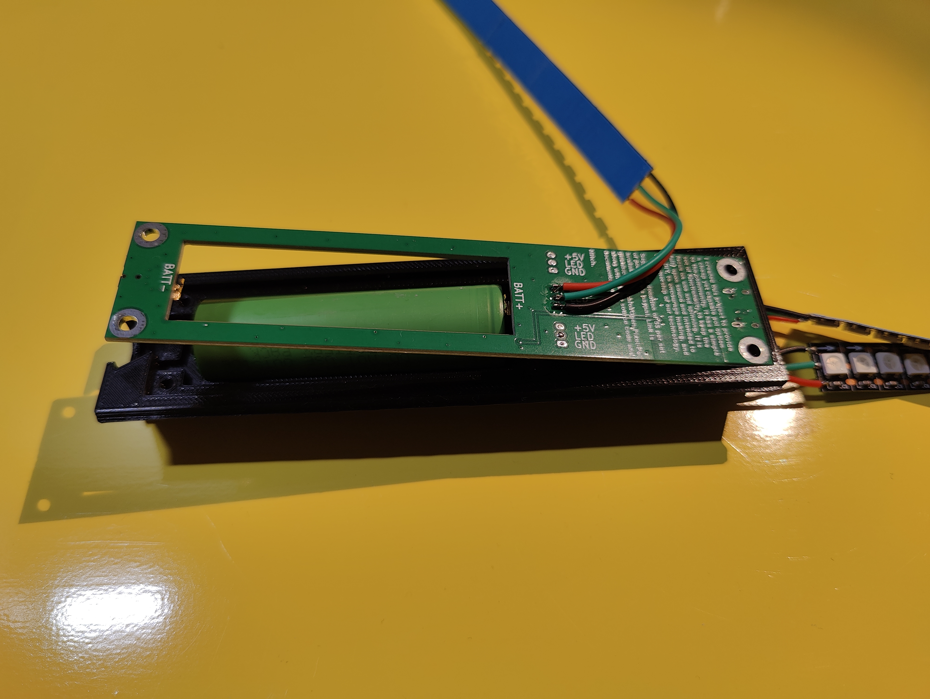
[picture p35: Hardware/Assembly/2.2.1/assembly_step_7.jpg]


## Step 8
### Snap the button into body
Push the button into the body, it is a snap fit.
> [!CAUTION]
> **Take extra care to avoid contact with the switch on bottom of the board!**
> **It can break easy.**

> [!TIP]
> After writing this guide, I came across a potentialy safer alternative assembly method. Place the button in before putting the PCB in, then hold the body vertically such that gravity lets the button fall to the down position. Then snap the board in without fear of tearing the switch off the pcb, as gravity holds the button away. Maybe this will be useful if someone is assembling many kits.

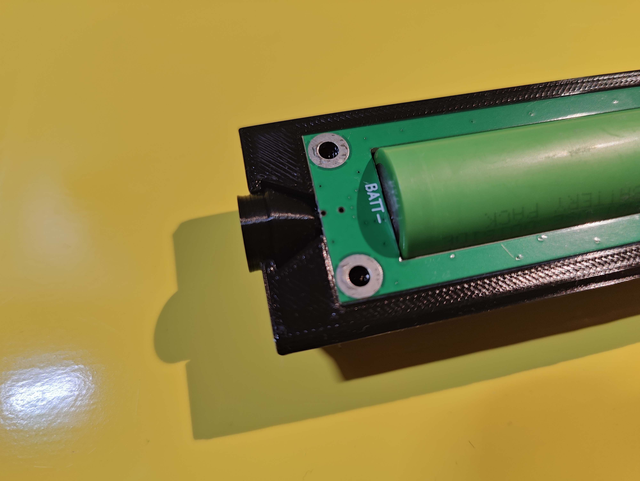
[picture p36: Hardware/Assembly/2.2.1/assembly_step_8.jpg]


## Step 9
### Thread the 3rd led strip through the bottom of the body
Same as the first 2, but easier, make sure it is twisted the right way.
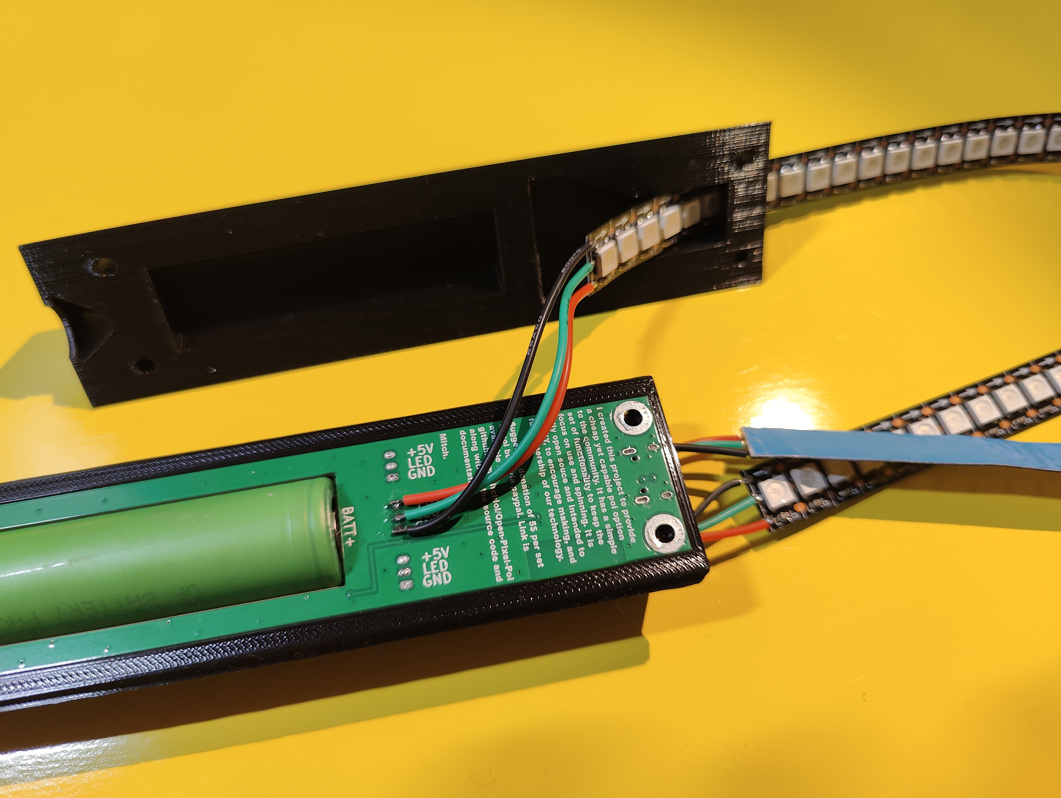
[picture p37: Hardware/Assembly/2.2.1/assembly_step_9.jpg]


## Step 10
### Push the 2 body halves together
Once again, the battery is snug. Make sure no wires get pinched.
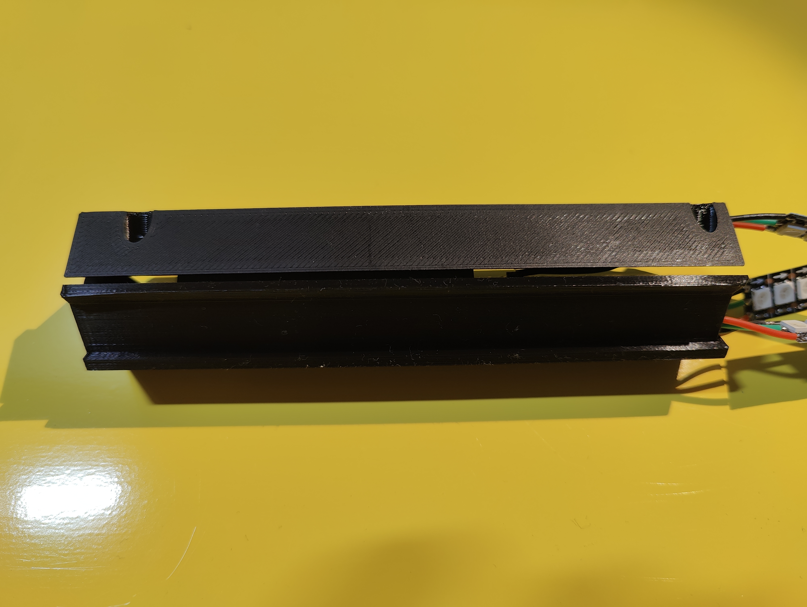
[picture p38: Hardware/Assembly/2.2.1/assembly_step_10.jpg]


## Step 11
### Screw the two halves together
These screws are going directly into a 3d print, so be gentle, you don't want to strip the threads. You can hold it up to the light to make sure there is no visible gap between the 2 halfs, to know it is snug.

Alternativley, you can just wrap the sucker in packing tape, just make sure you do it after sticking on the LEDs.
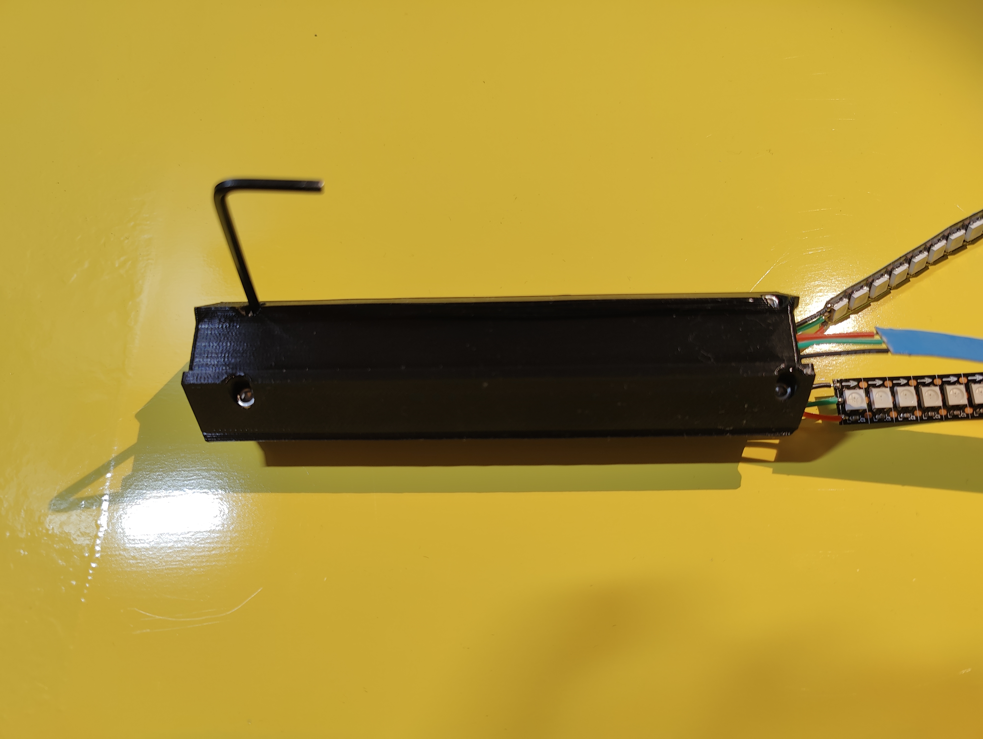
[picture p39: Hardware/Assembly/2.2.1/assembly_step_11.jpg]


## Step 12
### Apply the LED strips
Peel the backing off the LED strips, and apply to the to body. 
One for each recess. 
Start from the bottom of the poi and work back towards the wiring. 
If you cut the bottom of the strip flush with the bottom LED, it should line up perfectly.
Do this for all 3 strips.
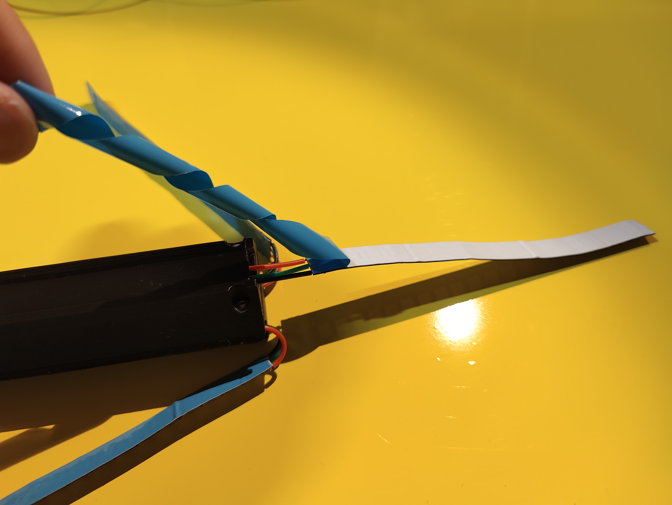
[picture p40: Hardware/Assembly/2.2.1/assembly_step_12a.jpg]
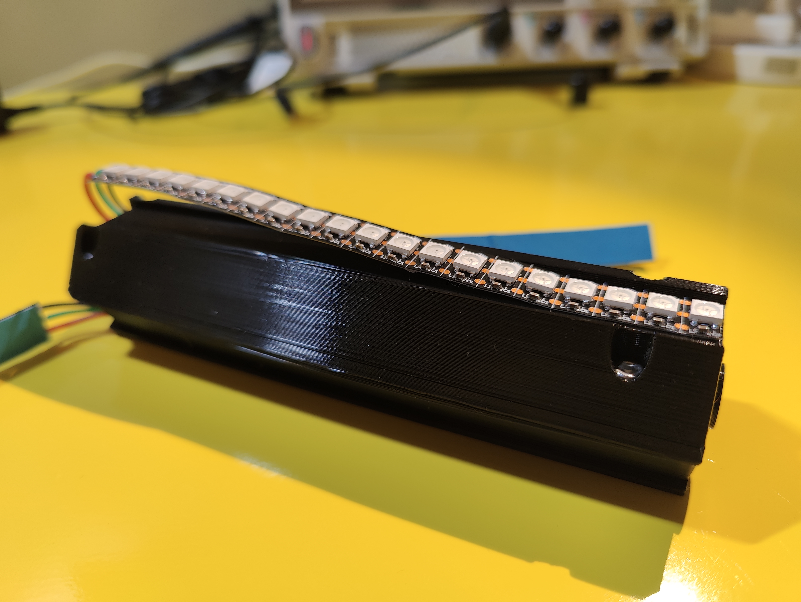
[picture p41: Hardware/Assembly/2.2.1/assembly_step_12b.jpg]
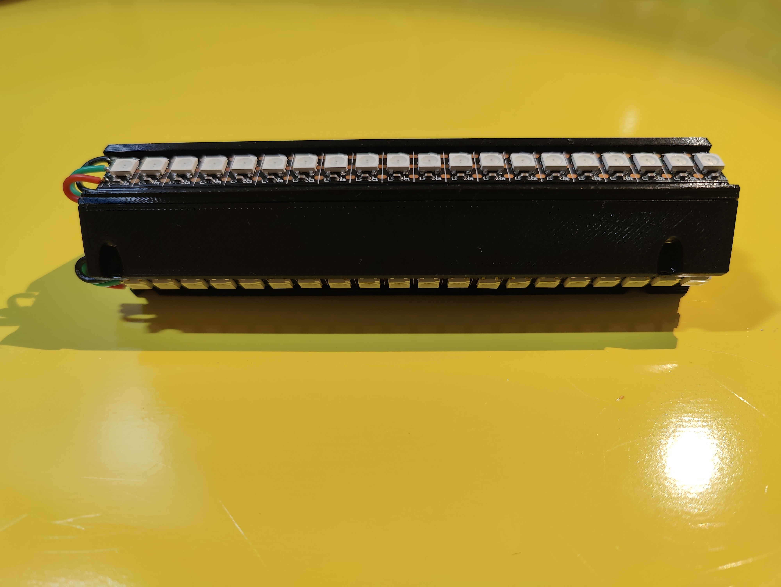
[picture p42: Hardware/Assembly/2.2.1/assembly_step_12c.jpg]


## Step 13
### Tuck excess wireing into the body
Using blunt tweezers makes light work of this.
I tuck the 2 top strips away from the exposed screws.
I don't think they can move enough to wear thorugh and cause a short. But you can add a dab of hot glue to ease your mind if you wish.
wiring

## Step 14
### Slot the body into the shell
Pull the two longer tabs apart to get the clearnace needed.
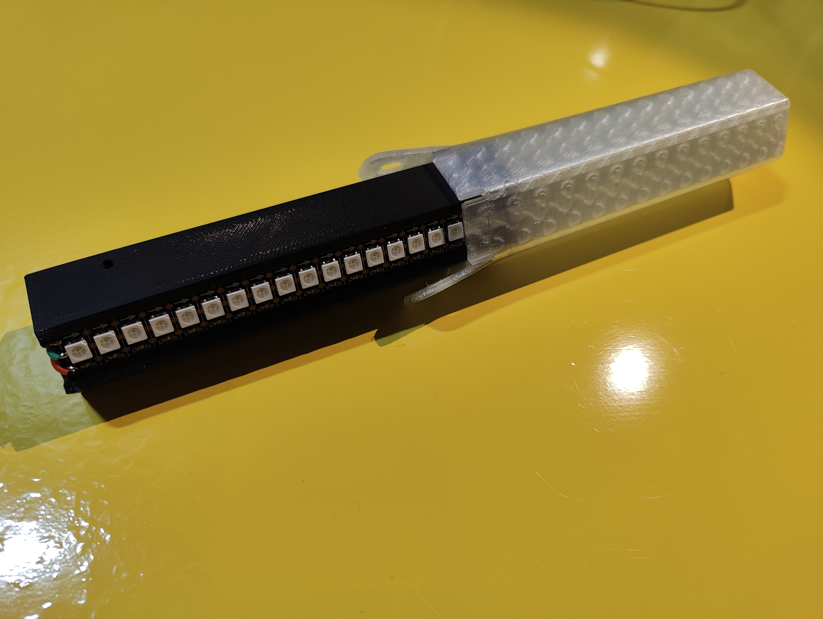
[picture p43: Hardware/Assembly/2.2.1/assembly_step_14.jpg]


## Step 15
### Party!
Woah! Where did that 2nd poi come from?
wiring

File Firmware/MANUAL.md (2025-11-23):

# Open Pixel Poi User Manual

> [!NOTE]  
> This guide is kept in sync with the firmare ware published to the 
> web-based firmware flasher tool. The PCBs from my web store may 
> arrive with outdated firmware, as they are pre-flashed in batches.

## Quirks & Features
Open pixel poi have a single button menu which gives access to

1. Power on/off
1. 15 pattern slots (split into 3 pattern banks w/ auto cycle options)
1. 5 Brightness levels
1. 10 speeds
1. Voltage display

Note: a freshly flashed firmware will have no pattens and display
a yellow strobe for all of the pattern slots, until they are 
filled via the [app](/Software/README.md).

Also Note: The lowest brightness level can only display primary 
colors, this means patterns and color based battery level will 
have very low fidelity. The second to lowest level can also
struggle a little. This concept is known as 
[color depth](https://en.wikipedia.org/wiki/Color_depth).

## Power On/Off
When off, a single button press will turn the poi on.
When on, a single press and hold will turn the poi off.

Note: When turning the poi off, the press andhold will initially
show the blue dot animation, followed by a green/yellow/red battery
level indicator, then the LEDs will do a single blink and fade 
out from the outer ends to the middle. You can release the button 
after the battery level blinks, and the poi will turn off when the 
animation completes.

## Changing Patterns
A single button press will show the blue dot animation, and then
change to the next pattern. After the 5th pattern, the poi will
loop back to the first pattern.

## Changing pattern banks
A single press, followed by a press and hold will show the pink
dot pattern cycling animation, and then ramp up through the pattern
bank slots. There are 3 slots, which hold 5 patterns each. Release
the hold at the desired bank to select it.

## Auto pattern cycling
When changing pattern banks, keep holding past the 3rd bank, and 
blue dots will appear indicating which bank(s) will be set to auto 
cycle. First (after the 3rd bank selection) is all 3, which will 
cycle all 15 patterns, followed by 1st, 2nd, and 3rd banks. 
Release the hold when the desired bank(s) are indicated and the 
poi will auto cycle the patterns in the sleected bank(s), 
changing the pattern every 10 seconds.

## Changing Brightness
A double press, followed by a press and hold will show the white
dot animation, and then ramp up through the brightness levels.
Release the hold at the desired brightness level to select it.

## Changing Speed
A tripple press, followed by a press and hold will show the red
dot animation, and then ramp up through the speed levels.
Release the hold at the desired speed level to select it.

## Battery level monitoring
A single press and hold will show the battery level as a color.
Green is full, red is empty, shades of yellow inbetween.
If you hold too long, it will go into the shutdown sequence.

Pressing the button 5 times which will show the green->red dot 
animation and enter the voltage display mode. In this mode the 
blue leds represent the integer value of the cell voltage, and
remanining leds represent the tenths of a volt fraction. The 
remaining leds are group into 3s for easier counting, and the
color varies from green to red based on the battery level.

## Low battery
When the battery level gets low (below 3.45v) the brightness will
be limited to level 3 max.

When the battery level gets critical (below 3.33v) the poi will
only display 2 red pixels at either end, at the miniumum level.

When the battery level gets even lower (3.25v) the poi will
automatically shut down.

## Charging
The poi charge via the USB-C port. When charging, a blue led will
light up on the pcb, to indicate charging status. The led's
illumination is visible through the wire holes at the top, and
through the reset hole on the side. The blue led will turn off
when charging is complete. The poi charge at a rate of 500ma.

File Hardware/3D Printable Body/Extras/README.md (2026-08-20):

# Open Pixel Poi - 3D Printed Extras

## Knobs
Some random knobs i designed with little thought or effort.
1. **Option 1:** [Poi Knob v1](<https://github.com/Mitchlol/Open-Pixel-Poi/raw/refs/heads/main/Hardware/3D%20Printable%20Body/Extras/Poi%20Knob%20v1.3mf>)
1. **Option 1:** [Poi Knob v2](<https://github.com/Mitchlol/Open-Pixel-Poi/raw/refs/heads/main/Hardware/3D%20Printable%20Body/Extras/Poi%20Knob%20v2.3mf>)

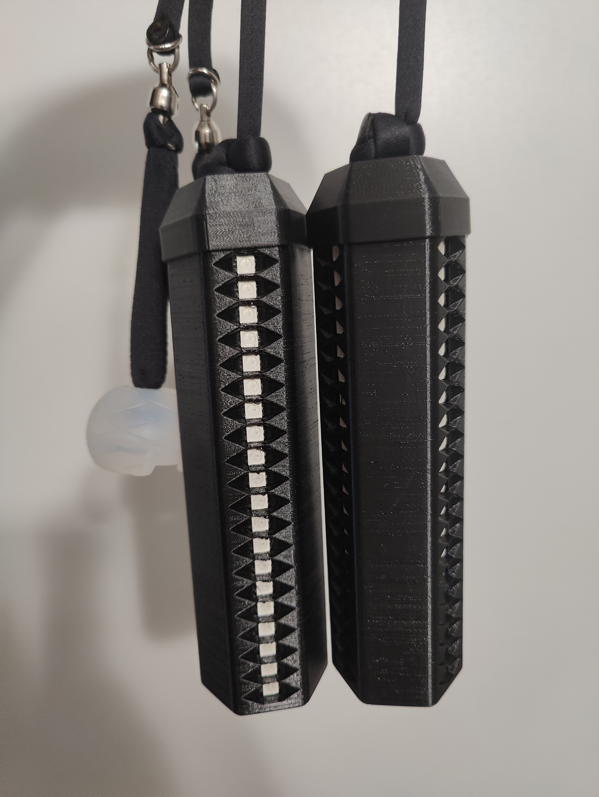
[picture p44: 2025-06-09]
Hardware/3D Printable Body/Extras/hex_holes.jpg

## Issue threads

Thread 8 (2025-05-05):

adding more Banks and Slots

KiWyFox, 2025-05-05:
Hi
First i like to thank you for this amazing project.
Currently printing  all the parts for the old(Seed Studio based) version.
does the round shell from new (pcb version) fit the old inner Part?

on the android app i discovered that there are very limited Banks and Pattern Slots.
is there a way i can change the code to get more banks and slots in each bank?
One bank for each style of image types we can add and each with 7 Slots would be awesome.
Some more suggestions;-)
- It would be usefull to see a border in diffrent color, around the bank and Slot, which is currently active
- when cycling trough all the patterns or banks, it would be nice to have to possibility to set the time for how long we see each pattern

KiWyFox, 2025-05-21:
Hi
meanwhile i made the changes in the Android App and for Button Interface(DS_Bank LED animation is working).
now i have 5 Banks with 7 Patterns in each bank.

maybe i can get some help for the last thing on my wish list?
- when cycling trough all the patterns or banks, it would be nice to have the possibility to set the time for how long we see each individual pattern(would help to program complete POI choreographys, synced to music)

otherwise feel free to close this issue..

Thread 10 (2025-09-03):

deep sleep

dudauduau, 2025-09-03:
Hi
I've made a pair.
I fully charged the POIs and put them in my drawer for storage.
After a week the INR 35e cells were fully discharged to 3.2V.
The deep sleep current of the esp32 or the TPS regulator needs to be way to high!
Since the charge current of 500nah is already very very low, i think this discharge issues should be fixed.
Don't like to wait 8h for a full charge when I like to play my pois.

Only idea I've at the moment is, to install an additional switch, that completely cuts off the battery from the rest of the electronics...

iilliio, 2025-09-05:
sounds like your regulator is not switching to deep sleep. in that case the leds would consume ±20% of the working current.
i'm using the following dc boost: https://www.aliexpress.com/item/1005001641295657.html?spm=a2g0o.order_list.order_list_main.20.7de91802YKcCxQ

i had to hack the code a bit to make the height adjustable and create a new BT command to send the current number of leds.
also had to modify the Flutter app (added this config there) and made sure the photos supplied are cut accordingly.
it works great with a 60px dense (240px/meter) COB led strip.

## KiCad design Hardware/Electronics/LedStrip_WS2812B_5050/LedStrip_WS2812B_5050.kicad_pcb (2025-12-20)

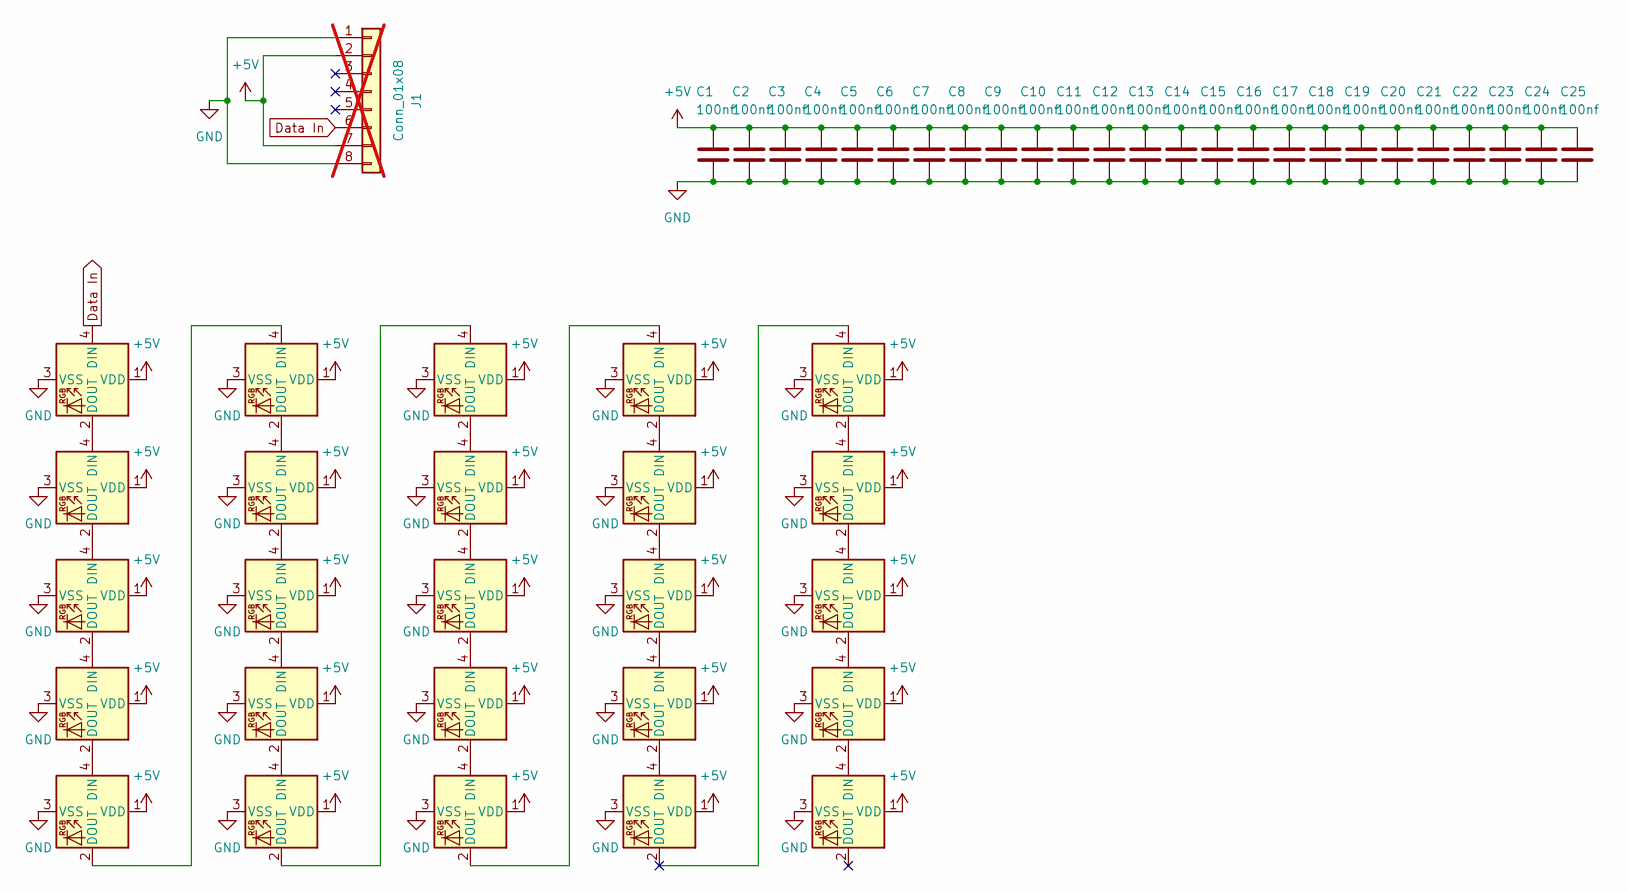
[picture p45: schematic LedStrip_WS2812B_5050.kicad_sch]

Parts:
C1, C2, C3, C4, C5, C6, C7, C8, C9, C10, C11, C12, C13, C14, C15, C16, C17, C18, C19, C20, C21, C22, C23, C24, C25: 100nf; C_0402_1005Metric; LCSC C1525
D1, D2, D3, D4, D5, D6, D7, D8, D9, D10, D11, D12, D13, D14, D15, D16, D17, D18, D19, D20, D21, D22, D23, D24, D25: WS2812B; LED_WS2812B_PLCC4_5.0x5.0mm_P3.2mm; LCSC C2843785
J1: Conn_01x08; FPC_01x08_conn; not fitted

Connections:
+5V: C1.1, C2.1, C3.1, C4.1, C5.1, C6.1, C7.1, C8.1, C9.1, C10.1, C11.1, C12.1, C13.1, C14.1, C15.1, C16.1, C17.1, C18.1, C19.1, C20.1, C21.1, C22.1, C23.1, C24.1, C25.1, D1.1 (VDD), D2.1 (VDD), D3.1 (VDD), D4.1 (VDD), D5.1 (VDD), D6.1 (VDD), D7.1 (VDD), D8.1 (VDD), D9.1 (VDD), D10.1 (VDD), D11.1 (VDD), D12.1 (VDD), D13.1 (VDD), D14.1 (VDD), D15.1 (VDD), D16.1 (VDD), D17.1 (VDD), D18.1 (VDD), D19.1 (VDD), D20.1 (VDD), D21.1 (VDD), D22.1 (VDD), D23.1 (VDD), D24.1 (VDD), D25.1 (VDD), J1.2, J1.7
Data In: D1.4 (DIN), J1.6
GND: C1.2, C2.2, C3.2, C4.2, C5.2, C6.2, C7.2, C8.2, C9.2, C10.2, C11.2, C12.2, C13.2, C14.2, C15.2, C16.2, C17.2, C18.2, C19.2, C20.2, C21.2, C22.2, C23.2, C24.2, C25.2, D1.3 (VSS), D2.3 (VSS), D3.3 (VSS), D4.3 (VSS), D5.3 (VSS), D6.3 (VSS), D7.3 (VSS), D8.3 (VSS), D9.3 (VSS), D10.3 (VSS), D11.3 (VSS), D12.3 (VSS), D13.3 (VSS), D14.3 (VSS), D15.3 (VSS), D16.3 (VSS), D17.3 (VSS), D18.3 (VSS), D19.3 (VSS), D20.3 (VSS), D21.3 (VSS), D22.3 (VSS), D23.3 (VSS), D24.3 (VSS), D25.3 (VSS), J1.1, J1.8
unnamed: D1.2 (DOUT), D2.4 (DIN)
unnamed: D2.2 (DOUT), D3.4 (DIN)
unnamed: D3.2 (DOUT), D4.4 (DIN)
unnamed: D4.2 (DOUT), D5.4 (DIN)
unnamed: D5.2 (DOUT), D6.4 (DIN)
unnamed: D6.2 (DOUT), D7.4 (DIN)
unnamed: D7.2 (DOUT), D8.4 (DIN)
unnamed: D8.2 (DOUT), D9.4 (DIN)
unnamed: D9.2 (DOUT), D10.4 (DIN)
unnamed: D10.2 (DOUT), D11.4 (DIN)
unnamed: D11.2 (DOUT), D12.4 (DIN)
unnamed: D12.2 (DOUT), D13.4 (DIN)
unnamed: D13.2 (DOUT), D14.4 (DIN)
unnamed: D14.2 (DOUT), D15.4 (DIN)
unnamed: D15.2 (DOUT), D16.4 (DIN)
unnamed: D16.2 (DOUT), D17.4 (DIN)
unnamed: D17.2 (DOUT), D18.4 (DIN)
unnamed: D18.2 (DOUT), D19.4 (DIN)
unnamed: D19.2 (DOUT), D20.4 (DIN)
unnamed: D21.2 (DOUT), D22.4 (DIN)
unnamed: D22.2 (DOUT), D23.4 (DIN)
unnamed: D23.2 (DOUT), D24.4 (DIN)
unnamed: D24.2 (DOUT), D25.4 (DIN)

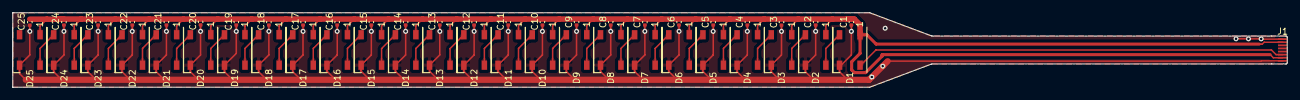
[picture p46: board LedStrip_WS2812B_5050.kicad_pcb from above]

Board: 2 copper layers, 205.2 x 12.0 mm, 51 parts (0 on the bottom side), 26 nets.

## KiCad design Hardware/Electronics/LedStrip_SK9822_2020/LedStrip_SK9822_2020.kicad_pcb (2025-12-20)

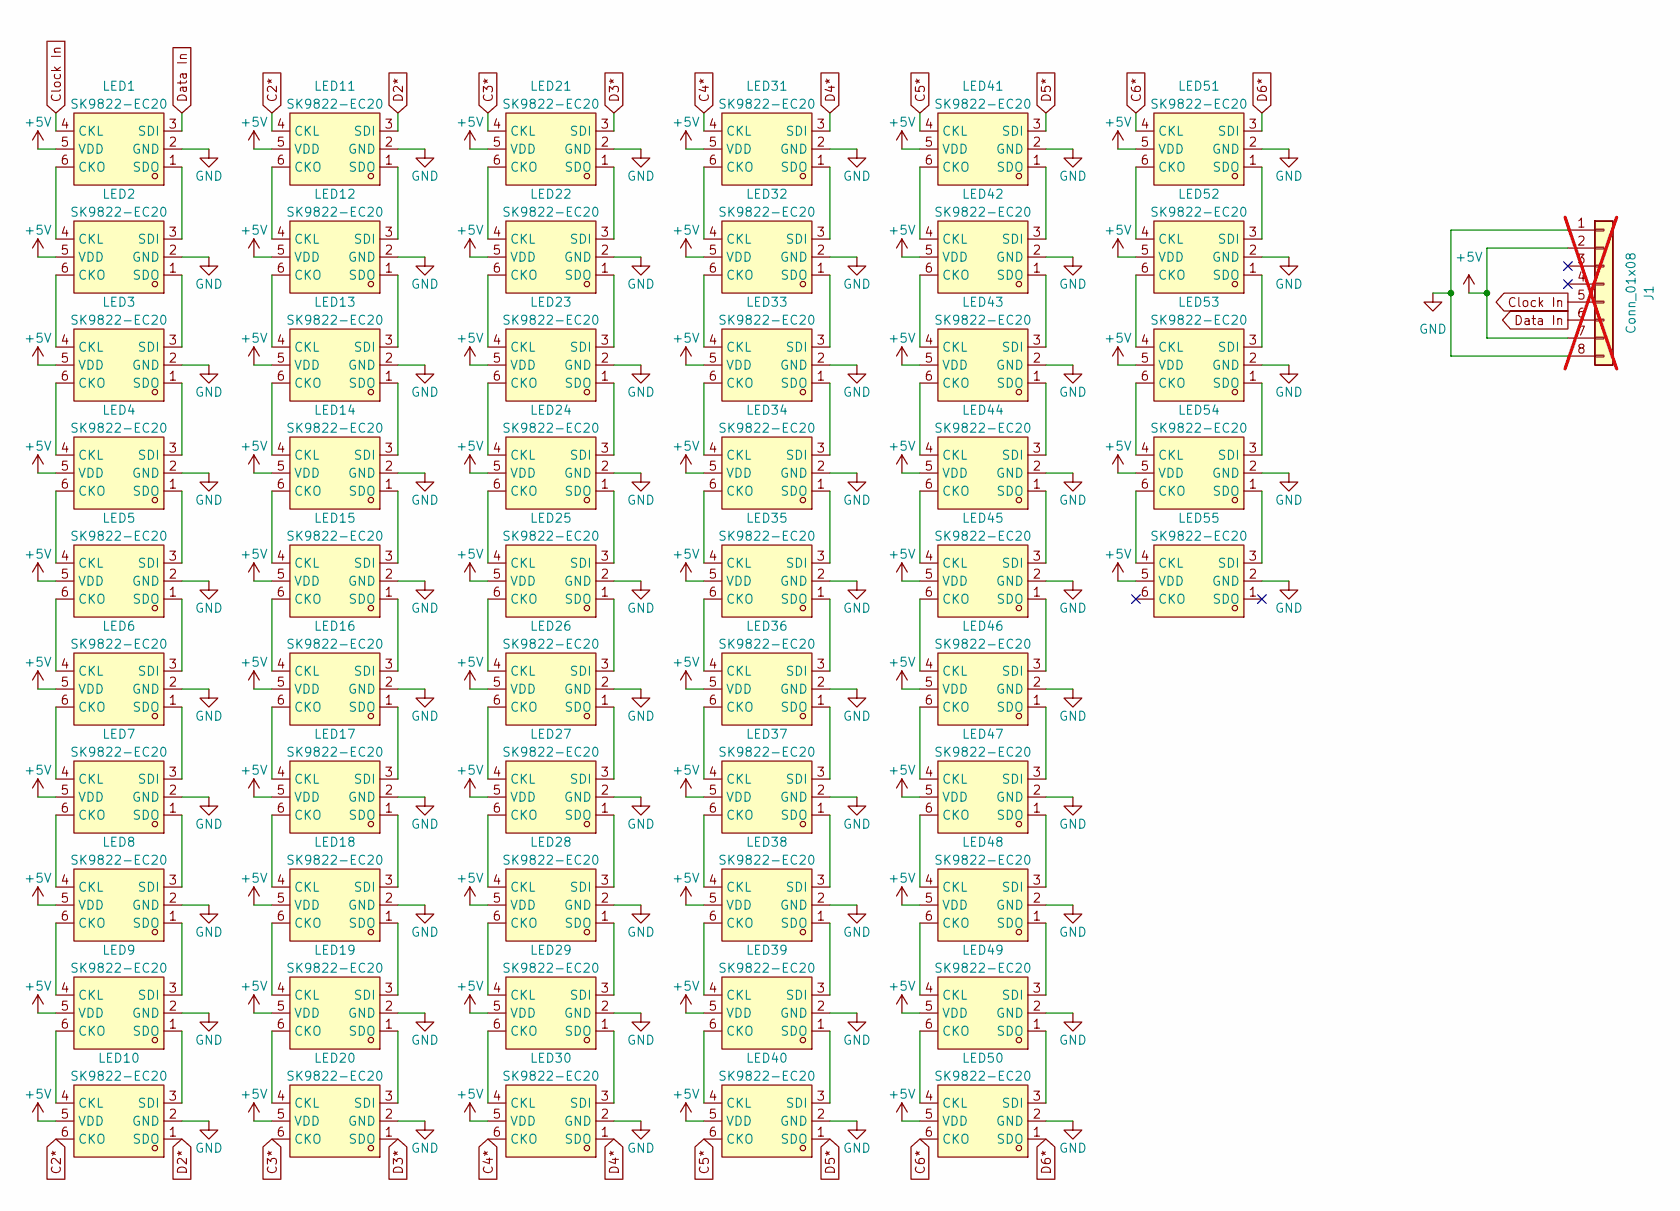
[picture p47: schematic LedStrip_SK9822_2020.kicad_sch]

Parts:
J1: Conn_01x08; FPC_01x08_conn; not fitted
LED1, LED2, LED3, LED4, LED5, LED6, LED7, LED8, LED9, LED10, LED11, LED12, LED13, LED14, LED15, LED16, LED17, LED18, LED19, LED20, LED21, LED22, LED23, LED24, LED25, LED26, LED27, LED28, LED29, LED30, LED31, LED32, LED33, LED34, LED35, LED36, LED37, LED38, LED39, LED40, LED41, LED42, LED43, LED44, LED45, LED46, LED47, LED48, LED49, LED50, LED51, LED52, LED53, LED54, LED55: SK9822-EC20; LED-SMD_6P-L2.0-W2.0-P0.80-TL; LCSC Part C2909059

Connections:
+5V: J1.2, J1.7, LED1.5 (VDD), LED2.5 (VDD), LED3.5 (VDD), LED4.5 (VDD), LED5.5 (VDD), LED6.5 (VDD), LED7.5 (VDD), LED8.5 (VDD), LED9.5 (VDD), LED10.5 (VDD), LED11.5 (VDD), LED12.5 (VDD), LED13.5 (VDD), LED14.5 (VDD), LED15.5 (VDD), LED16.5 (VDD), LED17.5 (VDD), LED18.5 (VDD), LED19.5 (VDD), LED20.5 (VDD), LED21.5 (VDD), LED22.5 (VDD), LED23.5 (VDD), LED24.5 (VDD), LED25.5 (VDD), LED26.5 (VDD), LED27.5 (VDD), LED28.5 (VDD), LED29.5 (VDD), LED30.5 (VDD), LED31.5 (VDD), LED32.5 (VDD), LED33.5 (VDD), LED34.5 (VDD), LED35.5 (VDD), LED36.5 (VDD), LED37.5 (VDD), LED38.5 (VDD), LED39.5 (VDD), LED40.5 (VDD), LED41.5 (VDD), LED42.5 (VDD), LED43.5 (VDD), LED44.5 (VDD), LED45.5 (VDD), LED46.5 (VDD), LED47.5 (VDD), LED48.5 (VDD), LED49.5 (VDD), LED50.5 (VDD), LED51.5 (VDD), LED52.5 (VDD), LED53.5 (VDD), LED54.5 (VDD), LED55.5 (VDD)
C2*: LED10.6 (CKO), LED11.4 (CKL)
C3*: LED20.6 (CKO), LED21.4 (CKL)
C4*: LED30.6 (CKO), LED31.4 (CKL)
C5*: LED40.6 (CKO), LED41.4 (CKL)
C6*: LED50.6 (CKO), LED51.4 (CKL)
Clock In: J1.5, LED1.4 (CKL)
D2*: LED10.1 (SDO), LED11.3 (SDI)
D3*: LED20.1 (SDO), LED21.3 (SDI)
D4*: LED30.1 (SDO), LED31.3 (SDI)
D5*: LED40.1 (SDO), LED41.3 (SDI)
D6*: LED50.1 (SDO), LED51.3 (SDI)
Data In: J1.6, LED1.3 (SDI)
GND: J1.1, J1.8, LED1.2 (GND), LED2.2 (GND), LED3.2 (GND), LED4.2 (GND), LED5.2 (GND), LED6.2 (GND), LED7.2 (GND), LED8.2 (GND), LED9.2 (GND), LED10.2 (GND), LED11.2 (GND), LED12.2 (GND), LED13.2 (GND), LED14.2 (GND), LED15.2 (GND), LED16.2 (GND), LED17.2 (GND), LED18.2 (GND), LED19.2 (GND), LED20.2 (GND), LED21.2 (GND), LED22.2 (GND), LED23.2 (GND), LED24.2 (GND), LED25.2 (GND), LED26.2 (GND), LED27.2 (GND), LED28.2 (GND), LED29.2 (GND), LED30.2 (GND), LED31.2 (GND), LED32.2 (GND), LED33.2 (GND), LED34.2 (GND), LED35.2 (GND), LED36.2 (GND), LED37.2 (GND), LED38.2 (GND), LED39.2 (GND), LED40.2 (GND), LED41.2 (GND), LED42.2 (GND), LED43.2 (GND), LED44.2 (GND), LED45.2 (GND), LED46.2 (GND), LED47.2 (GND), LED48.2 (GND), LED49.2 (GND), LED50.2 (GND), LED51.2 (GND), LED52.2 (GND), LED53.2 (GND), LED54.2 (GND), LED55.2 (GND)
unnamed: LED1.6 (CKO), LED2.4 (CKL)
unnamed: LED1.1 (SDO), LED2.3 (SDI)
unnamed: LED2.6 (CKO), LED3.4 (CKL)
unnamed: LED2.1 (SDO), LED3.3 (SDI)
unnamed: LED3.6 (CKO), LED4.4 (CKL)
unnamed: LED3.1 (SDO), LED4.3 (SDI)
unnamed: LED4.6 (CKO), LED5.4 (CKL)
unnamed: LED4.1 (SDO), LED5.3 (SDI)
unnamed: LED5.6 (CKO), LED6.4 (CKL)
unnamed: LED5.1 (SDO), LED6.3 (SDI)
unnamed: LED6.6 (CKO), LED7.4 (CKL)
unnamed: LED6.1 (SDO), LED7.3 (SDI)
unnamed: LED7.6 (CKO), LED8.4 (CKL)
unnamed: LED7.1 (SDO), LED8.3 (SDI)
unnamed: LED8.6 (CKO), LED9.4 (CKL)
unnamed: LED8.1 (SDO), LED9.3 (SDI)
unnamed: LED9.6 (CKO), LED10.4 (CKL)
unnamed: LED9.1 (SDO), LED10.3 (SDI)
unnamed: LED11.6 (CKO), LED12.4 (CKL)
unnamed: LED11.1 (SDO), LED12.3 (SDI)
unnamed: LED12.6 (CKO), LED13.4 (CKL)
unnamed: LED12.1 (SDO), LED13.3 (SDI)
unnamed: LED13.6 (CKO), LED14.4 (CKL)
unnamed: LED13.1 (SDO), LED14.3 (SDI)
unnamed: LED14.6 (CKO), LED15.4 (CKL)
unnamed: LED14.1 (SDO), LED15.3 (SDI)
unnamed: LED15.6 (CKO), LED16.4 (CKL)
unnamed: LED15.1 (SDO), LED16.3 (SDI)
unnamed: LED16.6 (CKO), LED17.4 (CKL)
unnamed: LED16.1 (SDO), LED17.3 (SDI)
unnamed: LED17.6 (CKO), LED18.4 (CKL)
unnamed: LED17.1 (SDO), LED18.3 (SDI)
unnamed: LED18.6 (CKO), LED19.4 (CKL)
unnamed: LED18.1 (SDO), LED19.3 (SDI)
unnamed: LED19.6 (CKO), LED20.4 (CKL)
unnamed: LED19.1 (SDO), LED20.3 (SDI)
unnamed: LED21.6 (CKO), LED22.4 (CKL)
unnamed: LED21.1 (SDO), LED22.3 (SDI)
unnamed: LED22.6 (CKO), LED23.4 (CKL)
unnamed: LED22.1 (SDO), LED23.3 (SDI)
unnamed: LED23.6 (CKO), LED24.4 (CKL)
unnamed: LED23.1 (SDO), LED24.3 (SDI)
unnamed: LED24.6 (CKO), LED25.4 (CKL)
unnamed: LED24.1 (SDO), LED25.3 (SDI)
unnamed: LED25.6 (CKO), LED26.4 (CKL)
unnamed: LED25.1 (SDO), LED26.3 (SDI)
unnamed: LED26.6 (CKO), LED27.4 (CKL)
unnamed: LED26.1 (SDO), LED27.3 (SDI)
unnamed: LED27.6 (CKO), LED28.4 (CKL)
unnamed: LED27.1 (SDO), LED28.3 (SDI)
unnamed: LED28.6 (CKO), LED29.4 (CKL)
unnamed: LED28.1 (SDO), LED29.3 (SDI)
unnamed: LED29.6 (CKO), LED30.4 (CKL)
unnamed: LED29.1 (SDO), LED30.3 (SDI)
unnamed: LED31.6 (CKO), LED32.4 (CKL)
unnamed: LED31.1 (SDO), LED32.3 (SDI)
unnamed: LED32.6 (CKO), LED33.4 (CKL)
unnamed: LED32.1 (SDO), LED33.3 (SDI)
unnamed: LED33.6 (CKO), LED34.4 (CKL)
unnamed: LED33.1 (SDO), LED34.3 (SDI)
unnamed: LED34.6 (CKO), LED35.4 (CKL)
unnamed: LED34.1 (SDO), LED35.3 (SDI)
unnamed: LED35.6 (CKO), LED36.4 (CKL)
unnamed: LED35.1 (SDO), LED36.3 (SDI)
unnamed: LED36.6 (CKO), LED37.4 (CKL)
unnamed: LED36.1 (SDO), LED37.3 (SDI)
unnamed: LED37.6 (CKO), LED38.4 (CKL)
unnamed: LED37.1 (SDO), LED38.3 (SDI)
unnamed: LED38.6 (CKO), LED39.4 (CKL)
unnamed: LED38.1 (SDO), LED39.3 (SDI)
unnamed: LED39.6 (CKO), LED40.4 (CKL)
unnamed: LED39.1 (SDO), LED40.3 (SDI)
unnamed: LED41.6 (CKO), LED42.4 (CKL)
unnamed: LED41.1 (SDO), LED42.3 (SDI)
unnamed: LED42.6 (CKO), LED43.4 (CKL)
unnamed: LED42.1 (SDO), LED43.3 (SDI)
unnamed: LED43.6 (CKO), LED44.4 (CKL)
unnamed: LED43.1 (SDO), LED44.3 (SDI)
unnamed: LED44.6 (CKO), LED45.4 (CKL)
unnamed: LED44.1 (SDO), LED45.3 (SDI)
unnamed: LED45.6 (CKO), LED46.4 (CKL)
unnamed: LED45.1 (SDO), LED46.3 (SDI)
unnamed: LED46.6 (CKO), LED47.4 (CKL)
unnamed: LED46.1 (SDO), LED47.3 (SDI)
unnamed: LED47.6 (CKO), LED48.4 (CKL)
unnamed: LED47.1 (SDO), LED48.3 (SDI)
unnamed: LED48.6 (CKO), LED49.4 (CKL)
unnamed: LED48.1 (SDO), LED49.3 (SDI)
unnamed: LED49.6 (CKO), LED50.4 (CKL)
unnamed: LED49.1 (SDO), LED50.3 (SDI)
unnamed: LED51.6 (CKO), LED52.4 (CKL)
unnamed: LED51.1 (SDO), LED52.3 (SDI)
unnamed: LED52.6 (CKO), LED53.4 (CKL)
unnamed: LED52.1 (SDO), LED53.3 (SDI)
unnamed: LED53.6 (CKO), LED54.4 (CKL)
unnamed: LED53.1 (SDO), LED54.3 (SDI)
unnamed: LED54.6 (CKO), LED55.4 (CKL)
unnamed: LED54.1 (SDO), LED55.3 (SDI)

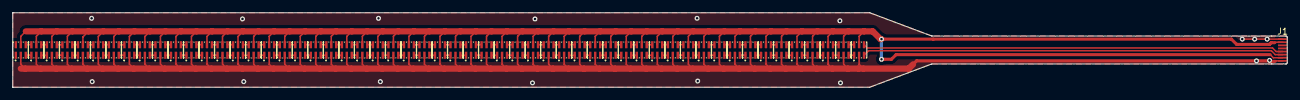
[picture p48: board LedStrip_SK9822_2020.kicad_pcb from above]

Board: 2 copper layers, 205.2 x 12.0 mm, 56 parts (0 on the bottom side), 112 nets.

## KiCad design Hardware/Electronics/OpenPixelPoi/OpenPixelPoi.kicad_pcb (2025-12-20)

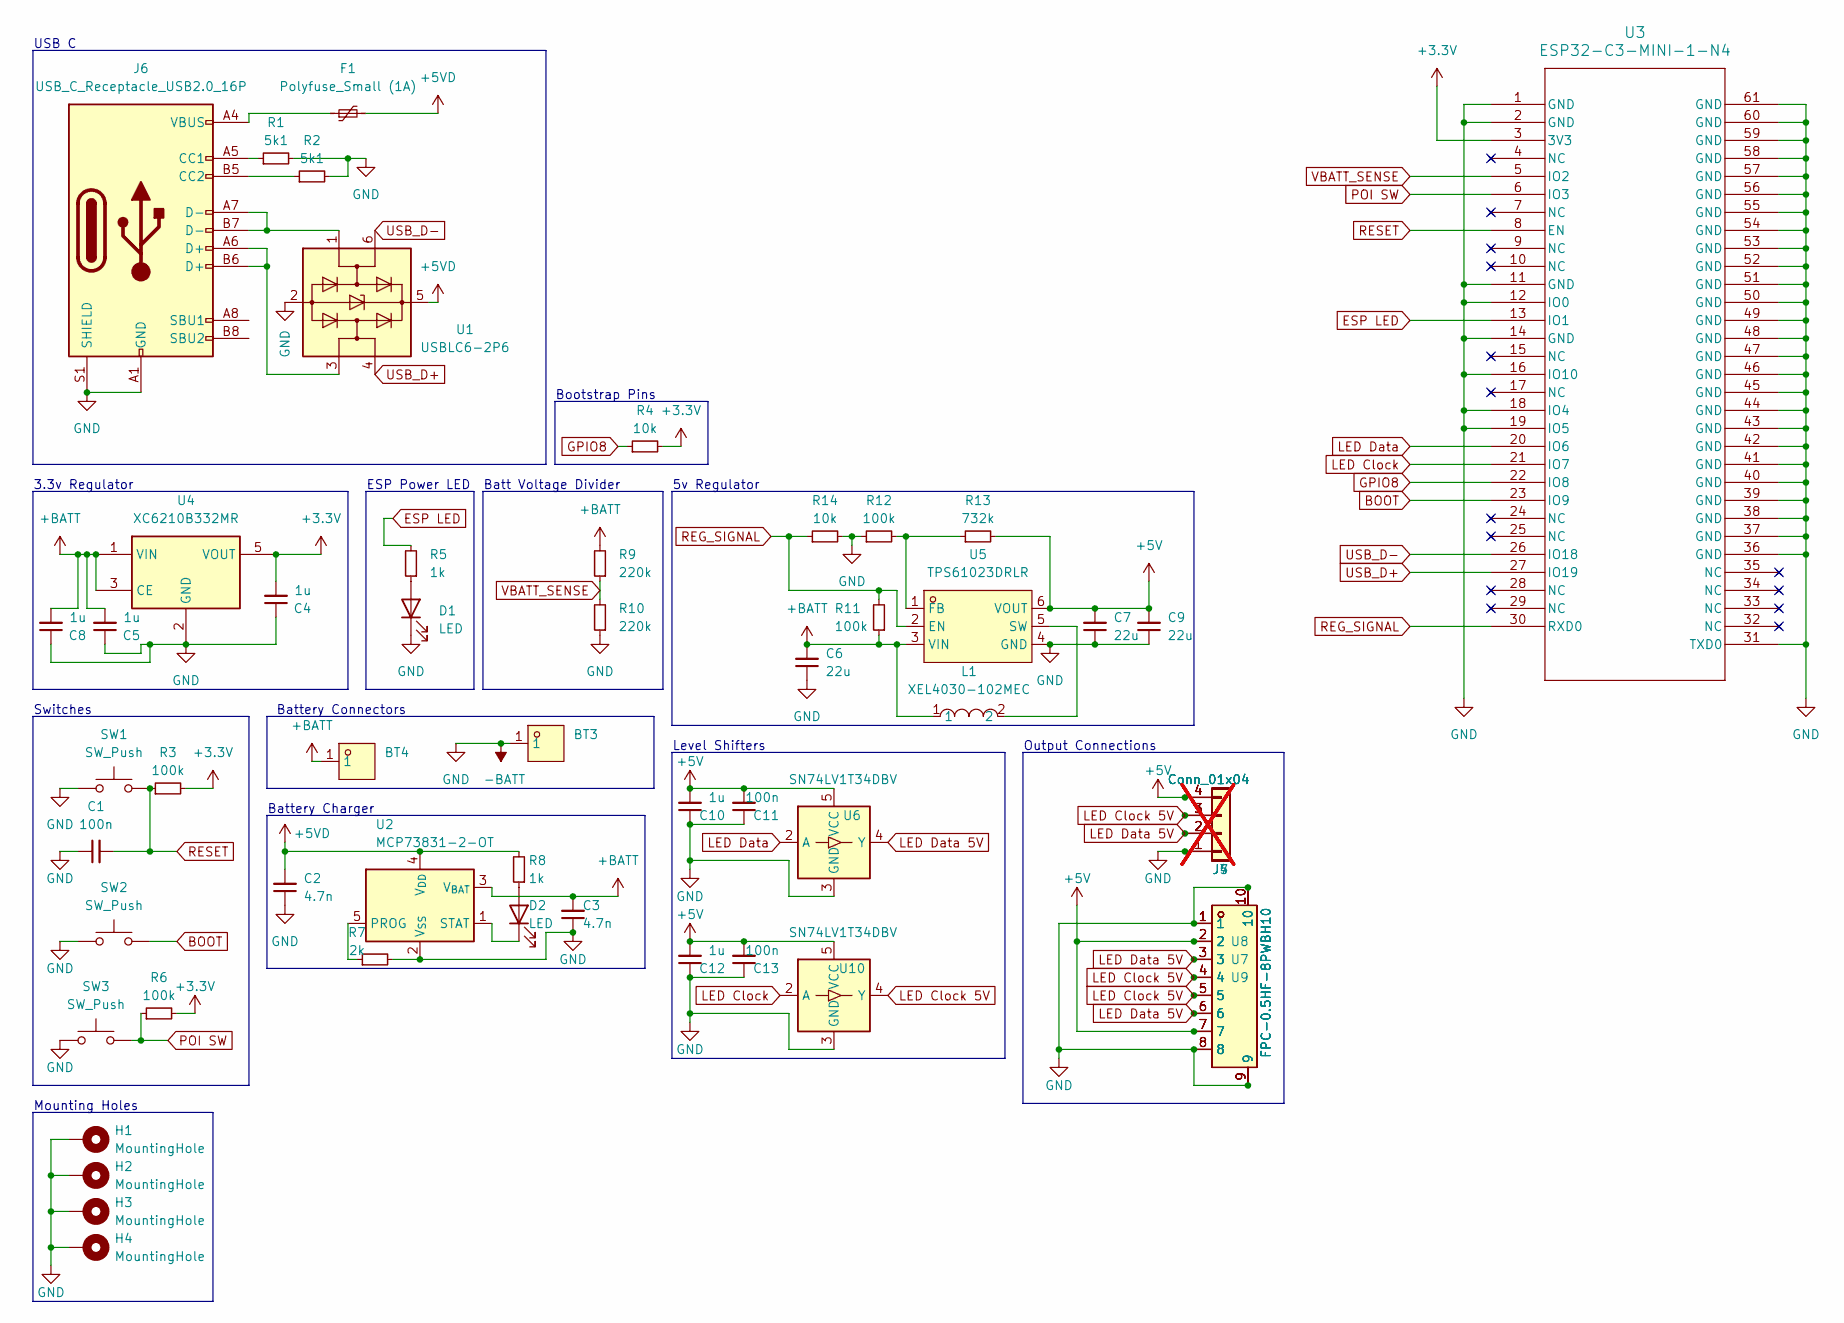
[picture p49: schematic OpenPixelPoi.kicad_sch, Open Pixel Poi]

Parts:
BT3, BT4: MY-ZJ-110; SMD_MY-ZJ-110; LCSC Part C964859
C1, C11, C13: 100n; C_0805_2012Metric; LCSC C83055
C2, C3: 4.7n; C_0805_2012Metric; LCSC C123621
C4, C5, C8, C10, C12: 1u; C_0805_2012Metric; LCSC C28323
C6, C7, C9: 22u; C_0805_2012Metric; LCSC C45783
D1, D2: LED; LED_0603_1608Metric; LCSC C965807
F1: Polyfuse_Small (1A); Fuse_1206_3216Metric; LCSC C720075
H1, H2, H3, H4: MountingHole; MountingHole_3.2mm_M3_Pad
J4, J5, J7: Conn_01x04; PinHeader_1x04_P2.00mm_Vertical; not fitted
J6: USB_C_Receptacle_USB2.0_16P; USB_C_Receptacle_HRO_TYPE-C-31-M-12; LCSC C2765186
L1: XEL4030-102MEC; IND-SMD_L4.0-W4.0-A; LCSC Part C5441341
R1, R2: 5k1; R_0603_1608Metric; LCSC C14677
R3, R6, R11, R12: 100k; R_0603_1608Metric; LCSC C14675
R4, R14: 10k; R_0603_1608Metric; LCSC C98220
R5, R8: 1k; R_0603_1608Metric; LCSC C22548
R7: 2k; R_0603_1608Metric; LCSC C22975
R9, R10: 220k; R_0603_1608Metric; LCSC C22961
R13: 732k; R_0603_1608Metric; LCSC C246003
SW1, SW2: SW_Push; SW_SPST_B3U-1000P; LCSC C19270949
SW3: SW_Push; Panasonic_EVQPUL_EVQPUC; LCSC C397351
U1: USBLC6-2P6; SOT-666; LCSC C15999
U2: MCP73831-2-OT; SOT-23-5; LCSC C424093
U3: ESP32-C3-MINI-1-N4; ESP32-C3-MINI-1_EXP; LCSC C2934569
U4: XC6210B332MR; SOT-23-5; LCSC C47719
U5: TPS61023DRLR; SOT-563_L1.6-W1.2-P0.50-LS1.6-BR; LCSC Part C919459
U6, U10: SN74LV1T34DBV; SOT-23-5; LCSC C100024
U7, U8, U9: FPC-0.5HF-8PWBH10; FPC-SMD_8P-P0.50_XUNPU_FPC-0.5HF-8PWBH10; LCSC Part C5343275

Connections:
+3.3V: C4.2, R3.2, R4.2, R6.2, U3.3 (3V3), U4.5 (VOUT)
+5V: C7.2, C9.2, C10.2, C11.2, C12.2, C13.2, J4.4, J5.4, J7.4, R13.2, U5.6 (VOUT), U6.5 (VCC), U7.2, U7.7, U8.2, U8.7, U9.2, U9.7, U10.5 (VCC)
+5VD: C2.2, F1.2, R8.2, U1.5 (VBUS), U2.4 (V_{DD})
+BATT: BT4.1, C3.2, C5.2, C6.2, C8.2, L1.1, R9.2, R11.1, U2.3 (V_{BAT}), U4.1 (VIN), U4.3 (CE), U5.3 (VIN)
-BATT: BT3.1, C1.1, C2.1, C3.1, C4.1, C5.1, C6.1, C7.1, C8.1, C9.1, C10.1, C11.1, C12.1, C13.1, D1.1 (K), H1.1, H2.1, H3.1, H4.1, J4.1, J5.1, J6.A1 (GND), J6.A12 (GND), J6.B1 (GND), J6.B12 (GND), J6.S1 (SHIELD), J7.1, R1.2, R2.2, R7.2, R10.1, R12.1, R14.2, SW1.1, SW2.1, SW3.1, U1.2 (GND), U2.2 (V_{SS}), U3.1 (GND), U3.2 (GND), U3.11 (GND), U3.12 (IO0), U3.14 (GND), U3.16 (IO10), U3.18 (IO4), U3.19 (IO5), U3.31 (TXD0), U3.36 (GND), U3.37 (GND), U3.38 (GND), U3.39 (GND), U3.40 (GND), U3.41 (GND), U3.42 (GND), U3.43 (GND), U3.44 (GND), U3.45 (GND), U3.46 (GND), U3.47 (GND), U3.48 (GND), U3.49 (GND), U3.50 (GND), U3.51 (GND), U3.52 (GND), U3.53 (GND), U3.54 (GND), U3.55 (GND), U3.56 (GND), U3.57 (GND), U3.58 (GND), U3.59 (GND), U3.60 (GND), U3.61 (GND), U4.2 (GND), U5.4 (GND), U6.3 (GND), U7.1, U7.8, U7.9, U7.10, U8.1, U8.8, U8.9, U8.10, U9.1, U9.8, U9.9, U9.10, U10.3 (GND)
BOOT: SW2.2, U3.23 (IO9)
ESP LED: R5.2, U3.13 (IO1)
GPIO8: R4.1, U3.22 (IO8)
LED Clock: U3.21 (IO7), U10.2 (A)
LED Clock 5V: J4.3, J5.3, J7.3, U7.4, U7.5, U8.4, U8.5, U9.4, U9.5, U10.4 (Y)
LED Data: U3.20 (IO6), U6.2 (A)
LED Data 5V: J4.2, J5.2, J7.2, U6.4 (Y), U7.3, U7.6, U8.3, U8.6, U9.3, U9.6
unnamed: D1.2 (A), R5.1
unnamed: D2.2 (A), R8.1
unnamed: D2.1 (K), U2.1 (STAT)
unnamed: F1.1, J6.A4 (VBUS), J6.A9 (VBUS), J6.B4 (VBUS), J6.B9 (VBUS)
unnamed: J6.A5 (CC1), R1.1
unnamed: J6.B5 (CC2), R2.1
unnamed: J6.A6 (D+), J6.B6 (D+), U1.3 (I/O2)
unnamed: J6.A7 (D-), J6.B7 (D-), U1.1 (I/O1)
unnamed: R7.1, U2.5 (PROG)
unnamed: R12.2, R13.1, U5.1 (FB)
unnamed: L1.2, U5.5 (SW)
POI SW: R6.1, SW3.2, U3.6 (IO3)
REG_SIGNAL: R11.2, R14.1, U3.30 (RXD0), U5.2 (EN)
RESET: C1.2, R3.1, SW1.2, U3.8 (EN)
USB_D+: U1.4 (I/O2), U3.27 (IO19)
USB_D-: U1.6 (I/O1), U3.26 (IO18)
VBATT_SENSE: R9.1, R10.2, U3.5 (IO2)

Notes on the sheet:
Battery Connectors
Output Connections
Batt Voltage Divider
Mounting Holes
Level Shifters
USB C
5v Regulator
3.3v Regulator
ESP Power LED
Bootstrap Pins
Switches
Battery Charger

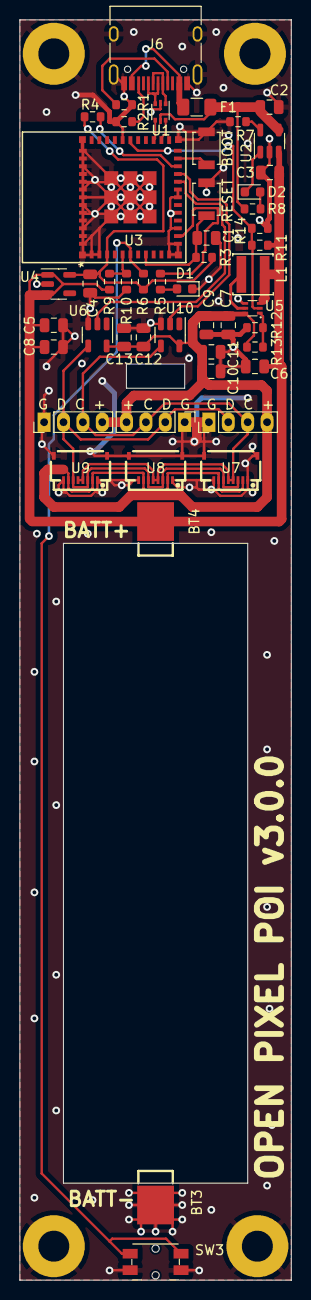
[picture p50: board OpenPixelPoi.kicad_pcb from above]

Board: 2 copper layers, 28.0 x 130.0 mm, 54 parts (0 on the bottom side), 29 nets.

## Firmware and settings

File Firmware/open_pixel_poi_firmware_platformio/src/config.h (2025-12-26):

#ifndef _CONFIG_H
#define _CONFIG_H

#define BATTERY_VOLTAGE_SENSOR true
#define BATTERY_VOLTAGE_LATCH 0.05
#define BATTERY_VOLTAGE_LOW 3.45
#define BATTERY_VOLTAGE_CRITICAL 3.33
#define BATTERY_VOLTAGE_SHUTDOWN 3.25

#define OUTPUT_PCB_CURRENT_LIMIT 1.2
#define OUTPUT_CHANNELS 3
#define OUTPUT_WS2812B_5050_DRAW 0.050
#define OUTPUT_WS2812B_5050_LIMIT 255
#define OUTPUT_SK9822_2020_DRAW 0.060
#define OUTPUT_SK9822_2020_LIMIT 100 // Data sheet says max brightness = 10/32 = 79/255, but yolo we do 100/255

// These limits max out the available space in the current partition scheme. They are also hardcoded in the app.
#define PATTERN_BANK_SIZE 5
#define PATTERN_BANK_COUNT 3
#define PATTERN_PIXEL_LIMIT 40000
#define PATTERN_SHUFFLE_DURATION 10 // This one is editable


#define DEFAULT_DEVICE_NAME "Open Pixel Poi"
#define BRIGHTNESS_OPTIONS (uint16_t[]){ 1, 4, 10, 25, 50, 100}


// Blank Canvas config (Defaults can be overriden with the bluetooth app)
#define DEFAULT_HARDWARE_VERSION 0 // 0 = no output, 1 = v2.2.1, 2 = v3.0.0
#define DEFAULT_LED_TYPE 0 // 0 = no output, 1 = Neo Pixel, 2 = Dot Star
#define DEFAULT_LED_COUNT 0
#define SPEED_OPTIONS (uint16_t[]){ 1, 3, 30, 100, 400, 600}

// Hardware kit 2.2.1 config
// #define DEFAULT_HARDWARE_VERSION 1 // 0 = no output, 1 = v2.2.1, 2 = v3.0.0
// #define DEFAULT_LED_TYPE 1 // 0 = no output, 1 = Neo Pixel, 2 = Dot Star
// #define DEFAULT_LED_COUNT 20
// #define SPEED_OPTIONS (uint16_t[]){ 1, 3, 30, 100, 400, 600}

// Hardware kit 3.0.0 25 NeoPixel config
// #define DEFAULT_HARDWARE_VERSION 2 // 0 = no output, 1 = v2.2.1, 2 = v3.0.0
// #define DEFAULT_LED_TYPE 1 // 0 = no output, 1 = Neo Pixel, 2 = Dot Star
// #define DEFAULT_LED_COUNT 25
// #define SPEED_OPTIONS (uint16_t[]){ 1, 3, 30, 150, 600, 800}

// Hardware kit 3.0.0 55 DotStar config
// #define DEFAULT_HARDWARE_VERSION 2 // 0 = no output, 1 = v2.2.1, 2 = v3.0.0
// #define DEFAULT_LED_TYPE 2 // 0 = no output, 1 = Neo Pixel, 2 = Dot Star
// #define DEFAULT_LED_COUNT 55
// #define SPEED_OPTIONS (uint16_t[]){ 1, 3, 30, 500, 1500, 2000}

#endif // _CONFIG_H

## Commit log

2025-05-21 Knobs and tweaks
    [Open Pixel Poi - Shell Cap - Round.3mf, Poi Knob v1.3mf, Poi Knob v2.3mf]
2025-06-09 Add more 3d files
    [Open Pixel Poi - Shell - Hex Holes.3mf, Open Pixel Poi - Shell - Round Superdiffuser.3mf, Open Pixel Poi - Shell Cap - Hex.3mf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]
2025-06-12 Add soldering video link
2025-08-07 Remove arduino ide, reduce shutdown timer.
2025-11-25 Add Clock pinout & FPC connectors to PCB, start on basic ws2812b LED strip.
    [kicad.kicad_pcb, kicad.kicad_sch, opp ws2812 fpc.kicad_pcb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]
2025-11-26 Add 20 and 55 pixel strips
    [bom.csv, designators.csv, kicad.kicad_pcb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]
2025-11-26 Add pullup to gpio8, change board "version" to 3.0.0 due to new data pinout.
    [kicad.kicad_pcb, kicad.kicad_sch]
2025-11-26 rename main kicad project
    [ESP32-C3-MINI-1-N4.step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]
2025-11-26 fix lib model links
    [OpenPixelPoi.kicad_pcb]
2025-11-26 Rename WS2812B project
    [LedStripWS2812B5050.kicad_pcb, LedStripWS2812B5050.kicad_sch, bom.csv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]
2025-11-26 Rename SK9822 led strip project
    [LedStrip_SK9822_2020.kicad_pcb, LedStrip_SK9822_2020.kicad_sch, bom.csv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]
2025-11-26 rerename ws2812 strip
    [LedStrip_WS2812B_5050.kicad_pcb, LedStrip_WS2812B_5050.kicad_sch, bom.csv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]
2025-11-26 Add higher density ws2812b strip
    [LedStrip_WS2812B_5050_V2.kicad_pcb, LedStrip_WS2812B_5050_V2.kicad_sch, bom.csv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]
2025-11-28 Switch to neopixel bus, add fw version checking, migrate to fw 2, 16bit fps values, change fw to app message format, fix fps bug, add config file, add preliminary support for sk9822/variable led coun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
    [config.h, open_pixel_poi_ble.cpp, open_pixel_poi_button.cpp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]
2025-11-29 Properly configurable led count, type, and hardware version
2025-11-29 Editable ble device names
2025-11-30 Import and load images of any aspect ratio with a max of 40000 pixels
    [opp_partitions.csv]
2025-12-16 Use 20Mhz hardware SPI for dotstar
2025-12-20 Add hex shell with no diffusion
    [Open Pixel Poi - Shell - Hex - 55 Pixel.3mf]
2025-12-20 Final pcb tweaks before large order
    [LedStrip_SK9822_2020.kicad_pcb, LedStrip_WS2812B_5050.kicad_pcb, OpenPixelPoi.kicad_pcb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]
2025-12-20 Fix slight lag every 2 seconds that has been annoying me for years
    [main.cpp]
2025-12-20 Switch spiffs to little FS and load patterns in chunks to reduce large lag spike on pattern change.
2025-12-21 Limit sk9822 to levels that dont cause retinal damage or melt the leds.
    [config.h, open_pixel_poi_led.cpp]
2025-12-21 Fix sequencer getting ahead of partially loaded images
    [open_pixel_poi_config.cpp]
2025-12-24 Include more shells and update 3d print readme
    [Open Pixel Poi - Shell - Hex Holes - 55 Pixel.3mf]
2025-12-30 Assembly readme improvements
2025-12-30 Add a little more space around button in an attempt to prevent them tearing off during removal
    [Open Pixel Poi - Body - Top.3mf]
2026-01-01 Update hex cap file to be easier to get on but not off.
    [Open Pixel Poi - Shell Cap - Hex.3mf]
2026-01-02 Break led strip code into seperate files
2026-01-07 Fix preference keys longer than 15 char limit
    [open_pixel_poi_config.cpp]
2026-01-08 Assembly Guide Imporvements
2026-01-08 Even better assembly guide
2026-01-23 Fix pattern looping desync
    [open_pixel_poi_config.cpp]
2026-02-11 Add Snap Cap Beta files.
    [Open Pixel Poi - Shell - Snap - 55 Pixel.3mf, Open Pixel Poi - Shell - Snap.3mf, Open Pixel Poi - Shell Cap - Snap A.3mf]
2026-02-13 Snap Cap B & some documentation
    [Open Pixel Poi - Shell Cap - Snap B.3mf]
2026-02-19 Adjust tolerances on snap caps for easier assembly, add 3rd cap with simple hole
    [Open Pixel Poi - Shell Cap - Snap A.3mf, Open Pixel Poi - Shell Cap - Snap B.3mf, Open Pixel Poi - Shell Cap - Snap C.3mf]
2026-02-19 Add chamfer to help lift snaps, update readme.
    [Open Pixel Poi - Shell Cap - Snap A.3mf, Open Pixel Poi - Shell Cap - Snap B.3mf]
2026-07-14 Make snapshell the official shell, move all old shell files to /OldShell
    [Open Pixel Poi - All Parts In One File.3mf, Open Pixel Poi - Shell - Hex - 55 Pixel.3mf, Open Pixel Poi - Shell - Hex Holes - 55 Pixel.3mf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]
2026-09-13 Fix all lints and modernize to current Dart and Flutter idioms
    Widgets now use final fields with state read from widget.* instead of
    passing values through State constructors, prints are debugPrint,
    BuildContext use across async gaps is guarded, foreach literals are
    for-in loops or collection-for, and enum and static member access uses
    the new dot shorthand syntax. The repetitive button grids in the home
    page and LabeledButtonSelect are collapsed into loops.
2026-09-13 Deduplicate repeated UI and serialization into shared code
    StatusMessage replaces ten identical saving/progress/message panels,
    ConnectionStateIndicators replaces the app bar actions boilerplate,
    BigButton and BigButtonRow replace the repeated bottom button rows,
    PatternPicker replaces six copies of the image selection block,
    DBImage.fromImg replaces three copies of the pixel serialization loop,
    and the seven hardware settings save flows share one _saveSetting.
    Also fixes the copied 'pixel count' error text shown for pixel type.
    BigButtonRow has a bounded height so it lays out inside a Column.
2026-09-13 Convert widget-returning helper methods into widget classes
    Every helper that built widgets is now either a proper widget class or
    inlined into the single build method that used it. New private widgets
    include the home page's transmit overlay, tab controls, command button
    grids, and pattern list, the welcome page's scan result list and bottom
    buttons, the hardware settings card and dropdown, the create page's
    creator button (the page itself is now stateless), and the color
    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
2026-09-13 Upgrade the Android toolchain to Gradle 9 and AGP 9
    Flutter 3.47 warns that support for Gradle 8.14.3, Android Gradle Plugin
    8.11.1 and Kotlin 2.2.20 will soon be dropped. Move all three to the
    versions the current Flutter template ships with.
    Android Gradle Plugin 9 and Kotlin 2.4 raise the old script deprecations
    to errors, so the app build script also has to move to the new DSL:
    kotlinOptions becomes a top level kotlin.compilerOptions block, and the
    explicit kotlin-android plugin is dropped because the Flutter Gradle
    Plugin already applies it.
    Gradle 9 always writes a problems report into the Android build
    directory, so ignore it.
